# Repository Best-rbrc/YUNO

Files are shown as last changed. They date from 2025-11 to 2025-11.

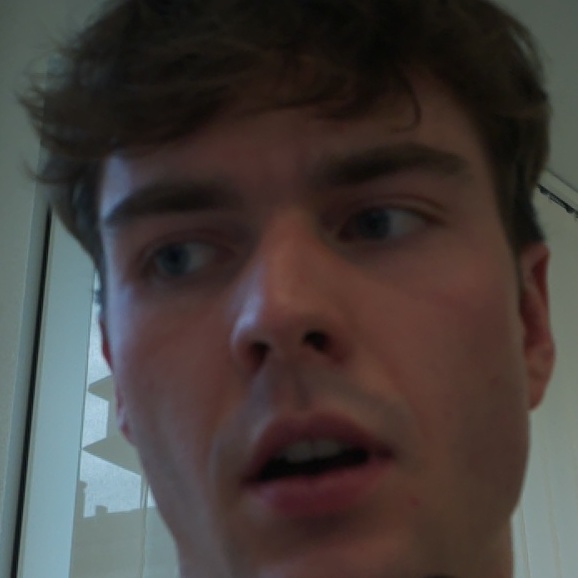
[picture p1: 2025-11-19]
waveshare/cache/photos/person_3.jpg

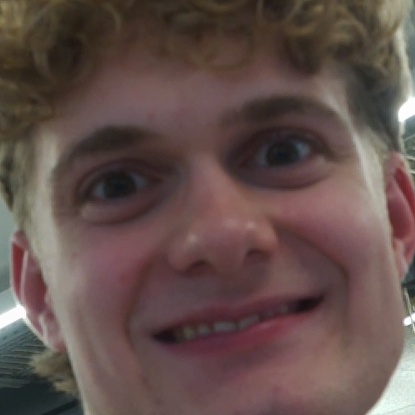
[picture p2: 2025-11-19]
waveshare/cache/photos/person_4.jpg

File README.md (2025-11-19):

# Yuno – Smart Person Recognition & Memory Assistant

Yuno is an intelligent face recognition system that helps you remember people and their context. The project consists of two independent Raspberry Pi systems and a web frontend, all syncing through Supabase as the single source of truth.

## What is Yuno?

**Yuno Glasses Prototype** (Raspberry Pi 1): A portable wearable system with camera, microphone, and Bluetooth speaker that recognizes faces, recalls context about people, and provides audio feedbac and rizz through physical button interactions.

**WaveShare Display Station** (Raspberry Pi 2): A 64x64 RGB LED matrix display showing pixel art portraits of recognized persons with an interactive quiz mode controlled via Arduino joystick.

**Web Dashboard**: A simple browser-based interface for managing persons, viewing photos, and editing context information.

## Key Features

- **Face Recognition**: ArcFace ONNX model with 512-dimensional embeddings and cosine similarity matching
- **Dual Raspberry Pi Architecture**: Independent systems syncing via Supabase (no direct Pi-to-Pi communication)
- **Button-Controlled Operation**: Physical buttons for enrollment and identification (Raspberry Pi 1)
- **Interactive Display**: 64x64 pixel art slideshow with quiz mode (Raspberry Pi 2)
- **Audio Feedback**: Text-to-speech via OpenAI TTS-1 or offline pyttsx3
- **Cloud Sync**: Supabase PostgreSQL database and cloud storage for photos/audio
- **Gender Detection**: DeepFace integration for demographic analysis
- **Rizz Mode**: AI-powered social interaction tips based on person context

---

## Documentation Structure

This project has **comprehensive documentation** across multiple README files:

### **[HARDWARE.md](HARDWARE.md)** - Complete Hardware Setup Guide
Detailed hardware requirements and assembly instructions for:
- **Raspberry Pi 1 (Yuno Glasses)**: Camera, microphone, Bluetooth speaker, physical buttons
- **Raspberry Pi 2 (WaveShare Display)**: 64x64 RGB LED matrix, MQTT broker setup
- **Arduino LCD Controller**: 16x2 display with joystick for quiz control
- Network architecture, MQTT configuration, power requirements, and wiring diagrams

👉 **Read HARDWARE.md for complete hardware setup instructions**

### **[src/README.md](src/README.md)** - Backend Technical Documentation
In-depth technical documentation for all backend modules:
- Face recognition pipeline (ArcFace, embedding generation, matching)
- Identity matching algorithms and similarity thresholds
- Database schema and Supabase integration
- OpenAI API integration (Whisper, GPT-4o-mini, TTS-1)
- Audio recording and speech output systems
- Button handler for Raspberry Pi GPIO
- All 14 core modules with code examples and usage patterns

👉 **Read src/README.md for backend development and API details**

### **[frontend/README.md](frontend/README.md)** - Web Frontend Documentation
Complete guide to the web dashboard:
- Vanilla JavaScript SPA architecture
- Supabase client integration and authentication
- Person management (CRUD operations)
- Photo upload and signed URL generation
- UI/UX design system and responsive layouts
- Context parsing and display logic

👉 **Read frontend/README.md for web interface development**

### **[waveshare/README.md](waveshare/README.md)** - Display System Documentation
WaveShare RGB LED matrix display system:
- Pixel art generation and LED optimization
- Multi-threaded architecture (display, MQTT, quiz, music)
- Quiz mode with OpenAI question generation
- MQTT joystick control integration
- Background music and TTS narration
- Configuration and operation modes

👉 **Read waveshare/README.md for display system details**

## Quick Start

1. Python 3.11 recommended
2. Create and activate a virtual environment
```bash
python -m venv venv
source venv/bin/activate  # macOS/Linux
# .\venv\Scripts\activate  # Windows PowerShell
```
3. Install dependencies
```bash
pip install -r requirements.txt
# If DeepFace/TensorFlow errors occur:
pip install tf-keras
```
4. Add configuration and keys
- Create `config/.env` with:
```
OPENAI_API_KEY=sk-...
SUPABASE_URL=https://YOUR-PROJECT.supabase.co
SUPABASE_KEY=YOUR_SERVICE_ROLE_OR_ANON_KEY
```
- Ensure `config/settings.yaml` exists (language etc.). Example:
```yaml
language: 'de'
```

5. Run
```bash
python main.py enroll             # Enroll new person (audio+photos)
python main.py identify           # Recognize and speak known persons
python main.py identify_local     # Recognize (console only)
python main.py add_face           # Add unknown faces (no audio)
python main.py rizz               # Rizz Mode (camera → gender → tips)
python main.py sync               # Sync local DB with Supabase
python main.py button             # Raspberry Pi button mode
```

---

##  Repository Structure

```
HandsOnHCI/
├── README.md                          # This file - project overview
├── HARDWARE.md                        # Complete hardware setup guide
├── requirements.txt                   # Python dependencies
├── main.py                            # CLI entry point for all operations
│
├── config/                            # Configuration files
│   ├── .env                           # API keys (OpenAI, Supabase) - create this!
│   ├── .env.example                   # Example environment variables template
│   └── settings.yaml                  # App settings (language, thresholds, etc.)
│
├── models/                            # Pre-trained models
│   ├── w600k_r50.onnx                 # ArcFace face recognition model (required)
│   └── README.md                      # Model information and download links
│
├── data/                              # Local data storage (auto-created)
│   ├── database/                      # SQLite database
│   │   └── memory.db                  # Local person database
│   ├── persons/                       # Enrolled person folders
│   │   └── person_X_Name/             # Individual person data
│   │       ├── faces/                 # Face images for training
│   │       ├── embeddings/            # Face embeddings (512-dim vectors)
│   │       └── audio/                 # Audio recordings
│   ├── photos/                        # Temporary photo storage
│   ├── audio/                         # Temporary audio recordings
│   └── temp/                          # Temporary processing files
│
├── src/                               # Backend source code
│   ├── README.md                      # 📖 Detailed backend documentation
│   ├── camera_manager.py              # Camera capture and frame processing
│   ├── face_recognizer.py             # Face detection and embedding generation
│   ├── identity_matcher.py            # Cosine similarity matching (threshold 0.45)
│   ├── database_handler.py            # SQLite database operations
│   ├── person_manager.py              # Person enrollment and identification
│   ├── gender_detector.py             # DeepFace gender/age/emotion detection
│   ├── rizz_mode.py                   # Social interaction tips generation
│   ├── rizz_orchestrator.py           # Rizz mode pipeline
│   ├── openai_api.py                  # OpenAI API (Whisper, GPT-4o, TTS-1)
│   ├── speech_output.py               # Audio playback (pygame, pyttsx3)
│   ├── audio_recorder.py              # Microphone recording (sounddevice)
│   ├── supabase_handler.py            # Supabase database and storage client
│   ├── sync_manager.py                # Bidirectional sync (local ↔ Supabase)
│   ├── input_handler.py               # Raspberry Pi GPIO button handler
│   └── path_manager.py                # File path management utilities
│
├── frontend/                          # Web dashboard
│   ├── README.md                      # 📖 Frontend documentation
│   ├── index.html                     # Single-page web application
│   ├── SUPABASE_SETUP.md              # Supabase configuration guide
│   └── src/
│       └── components/
│           └── PersonCard.jsx         # React component (if migrating)
│
├── waveshare/                         # RGB LED matrix display system
│   ├── README.md                      # 📖 WaveShare display documentation
│   ├── main_app.py                    # Main display application (700+ lines)
│   ├── data_loader.py                 # Fetch persons from Supabase
│   ├── pixel_art_generator.py         # Convert photos to 64x64 pixel art
│   ├── cache/                         # Photo cache directory
│   │   └── photos/                    # Cached person photos (person_X.jpg)
│   ├── sounds/                        # Background music playlist (.wav files)
│   └── simulation_output/             # Test output for debugging
│
├── Arduino/                           # Arduino firmware
│   └── Commands_Senden_UP_RIGHT_LEFT_DOWN/
│       └── Commands_Senden_UP_RIGHT_LEFT_DOWN.ino
│           # Arduino UNO R4 WiFi firmware for LCD display and joystick
│           # Connects to MQTT broker on Raspberry Pi 2 (WaveShare)
│           # Controls: UP/DOWN/LEFT/RIGHT joystick + button press
│           # Displays: Person name and description on 16x2 LCD
│
└── tests/                             # Test scripts for development
    ├── test_face_detection.py         # Test face detection on static images
    ├── test_face_identification.py    # Test face recognition accuracy
    ├── test_face_identification_with_context.py  # Test with person context
    ├── test_gender_detection.py       # Test gender detection on images
    ├── test_gender_video.py           # Test gender detection on video stream
    └── test_gender_with_pickuplines.py  # Test Rizz mode pipeline
```

---

## Quick Start

### Prerequisites
- **Python 3.11+** recommended
- **Raspberry Pi OS** (for hardware systems) or macOS/Linux (for development)
- **Supabase Account** (free tier sufficient)
- **OpenAI API Key** (for TTS and AI features)

### Installation

1. **Clone the repository**:
   ```bash
   git clone https://github.com/Best-rbrc/HandsOnHCI.git
   cd HandsOnHCI
   ```

2. **Create virtual environment**:
   ```bash
   python3 -m venv venv
   source venv/bin/activate  # macOS/Linux
   # .\venv\Scripts\activate  # Windows
   ```

3. **Install dependencies**:
   ```bash
   pip install -r requirements.txt
   # If DeepFace/TensorFlow errors:
   pip install tf-keras
   ```

4. **Configure environment**:
   Create `config/.env` (copy from `config/.env.example`):
   ```bash
   OPENAI_API_KEY=sk-proj-your-api-key-here
   SUPABASE_URL=https://your-project.supabase.co
   SUPABASE_KEY=your-anon-public-key
   ```

5. **Adjust settings** (optional):
   Edit `config/settings.yaml`:
   ```yaml
   language: 'de'  # or 'en'
   similarity_threshold: 0.45
   ```

### Usage Commands

```bash
# Enroll a new person (camera + audio + context)
python main.py enroll

# Identify a person (camera + TTS feedback)
python main.py identify

# Identify without audio (console output only)
python main.py identify_local

# Add face photos only (no audio/context)
python main.py add_face

# Rizz Mode (gender detection + social tips)
python main.py rizz

# Sync local database with Supabase
python main.py sync

# Raspberry Pi button mode (GPIO control)
python main.py button
```

### Hardware Systems

**Raspberry Pi 1 (Yuno Glasses)**:
```bash
# Run in button mode (wait for GPIO button press)
python main.py button
# Press Normal Button (GPIO 17) → Identify
# Press Heartbeat Button (GPIO 27) → Enroll
```

**Raspberry Pi 2 (WaveShare Display)**:
```bash
cd waveshare
python main_app.py
# Displays person slideshow with quiz mode
# Controlled via Arduino joystick (MQTT)
```

**Arduino LCD Controller**:
- Upload firmware from `Arduino/Commands_Senden_UP_RIGHT_LEFT_DOWN/`
- Configure WiFi and MQTT broker IP (Raspberry Pi 2)
- Joystick controls quiz navigation on WaveShare display

---

## Configuration Files

### `config/.env` - API Keys and Secrets
```bash
# OpenAI (required for TTS and text generation)
OPENAI_API_KEY=sk-proj-...

# Supabase (required for cloud sync and frontend)
SUPABASE_URL=https://your-project.supabase.co
SUPABASE_KEY=your-anon-or-service-role-key

# Optional: Raspberry Pi GPIO pins
NORMAL_BUTTON_PIN=17
HEARTBEAT_BUTTON_PIN=27
```

### `config/settings.yaml` - Application Settings

This YAML file controls various runtime parameters for the Yuno system:

```yaml
# Audio Recording Settings
record_duration: 20               # Duration in seconds for audio recording during enrollment
                                  # Used when capturing person context via microphone

# Language Settings
language: "de"                    # Language for TTS output and AI responses ('de' or 'en')
                                  # Affects OpenAI TTS voice and GPT response language

# File Paths (relative to project root)
photo_path: "data/photos/"        # Directory for temporary photo storage during capture
audio_path: "data/audio/"         # Directory for temporary audio recordings
database_path: "data/memory.db"   # SQLite database location (not used if Supabase sync active)

# Audio Hardware Configuration (Raspberry Pi specific)
audio_samplerate: 48000           # Sample rate in Hz (48 kHz standard for USB microphones)
                                  # Note: 44.1 kHz may not work with certain USB devices
audio_device_name: "AB13X USB Audio"  # Explicit USB microphone device name
                                  # Alternative ALSA format: "hw:2,0" (Card 2, Device 0)
                                  # Use `arecord -l` on Raspberry Pi to list available devices
```

**Common Configuration Adjustments**:

- **Change language**: Set `language: "en"` for English TTS and responses
- **Longer context recording**: Increase `record_duration: 30` for more detailed descriptions
- **Different microphone**: Update `audio_device_name` to match your USB device (check with `arecord -l`)
- **Audio issues**: Try different `audio_samplerate` values (44100, 48000, 96000) if recording fails

**Note**: The `database_path` setting is primarily for standalone/offline mode. When Supabase is configured in `.env`, the system automatically syncs with the cloud database.

---

## Testing

The `tests/` folder contains various test scripts for development:

- **`test_face_detection.py`**: Test face detection on static images
- **`test_face_identification.py`**: Test face recognition accuracy on enrolled persons
- **`test_face_identification_with_context.py`**: Test identification with context display
- **`test_gender_detection.py`**: Test gender detection on individual images
- **`test_gender_video.py`**: Test real-time gender detection on video stream
- **`test_gender_with_pickuplines.py`**: Test complete Rizz mode pipeline

Run tests:
```bash
python tests/test_face_detection.py
python tests/test_gender_video.py
```

---

## Database & Cloud Sync

### Supabase Schema
**Table: `persons`**
- `id` (int, primary key)
- `name` (text)
- `gender` (text)
- `context` (text) - Description/notes about the person
- `photo_url` (text) - Public URL to profile photo in Supabase Storage
- `audio_url` (text, optional) - URL to audio recording
- `created_at` (timestamp)

**Storage Buckets**:
- `person-photos`: Profile photos (private, use signed URLs)
- `person-audio`: Audio recordings (optional)

### Sync Behavior
- **Enroll/Identify on Pi 1**: Automatically syncs to Supabase
- **WaveShare Display (Pi 2)**: Fetches persons from Supabase every 5 minutes
- **Frontend**: Directly queries Supabase via JavaScript client
- **Conflict Resolution**: Supabase is the single source of truth

---

## Frontend Dashboard

Access the web dashboard:
```bash
# Option 1: Direct file access
open frontend/index.html  # macOS
start frontend/index.html  # Windows

# Option 2: HTTP server
cd frontend
python3 -m http.server 8000
# Open http://localhost:8000
```

Features:
- View all enrolled persons
- Edit person name and context
- Upload new photos
- Delete persons
- Real-time sync with Supabase
 **See [frontend/README.md](frontend/README.md) for detailed usage**

---

## Development Notes

### Project Structure Philosophy
- **Modular Architecture**: Each module has a single responsibility
- **Supabase as SSoT**: All systems sync via Supabase, no direct inter-Pi communication
- **Dual Operation Modes**: Standalone (Raspberry Pi) and development (Mac/PC)
- **Hardware Abstraction**: Same codebase runs on Pi and desktop with minimal changes

### Key Technologies
- **Face Recognition**: ArcFace ONNX (w600k_r50 model)
- **Face Detection**: OpenCV with Haar cascades
- **Gender/Age Detection**: DeepFace with TensorFlow backend
- **Cloud Backend**: Supabase (PostgreSQL + Storage)
- **AI Services**: OpenAI (Whisper, GPT-4o-mini, TTS-1)
- **Audio**: sounddevice, pygame, pyttsx3
- **Hardware**: Raspberry Pi GPIO, WaveShare RGB LED matrix, Arduino WiFi

### Adding New Features
1. **Backend**: Add module to `src/` and document in `src/README.md`
2. **Frontend**: Extend `frontend/index.html` and update `frontend/README.md`
3. **Hardware**: Update `HARDWARE.md` with wiring and setup instructions
4. **Tests**: Create test script in `tests/` folder

---

## Troubleshooting

### Common Issues

**DeepFace/TensorFlow Error**:
```bash
pip install tf-keras
```

**Camera Not Detected**:
```bash
# Check available cameras
ls /dev/video*  # Linux/Pi
# Or try different camera_index in settings.yaml
```

**Supabase Connection Failed**:
- Verify `SUPABASE_URL` and `SUPABASE_KEY` in `.env`
- Check internet connection
- Ensure Supabase project is active

**Frontend Images Not Loading**:
- Check Supabase Storage bucket permissions
- Ensure signed URLs are generated correctly
- Verify RLS policies allow public access

**MQTT Connection Timeout** (Arduino ↔ Pi 2):
- Verify Raspberry Pi 2 IP address in Arduino code
- Check Mosquitto broker is running: `sudo systemctl status mosquitto`
- Test MQTT: `mosquitto_sub -h localhost -t '#'`

**GPIO Permission Denied** (Raspberry Pi):
```bash
sudo usermod -aG gpio $USER
sudo reboot
```

---

## License & Attribution

- **ArcFace Model**: w600k_r50.onnx from [InsightFace](https://github.com/deepinsight/insightface)
- **DeepFace**: [serengil/deepface](https://github.com/serengil/deepface)
- **Supabase**: [supabase.io](https://supabase.io)
- **OpenAI**: [platform.openai.com](https://platform.openai.com)

---

## Quick Links

-  **[HARDWARE.md](HARDWARE.md)** - Complete hardware setup guide
-  **[src/README.md](src/README.md)** - Backend technical documentation
-  **[frontend/README.md](frontend/README.md)** - Web dashboard guide
-  **[waveshare/README.md](waveshare/README.md)** - Display system documentation
-  **[Arduino Firmware](Arduino/Commands_Senden_UP_RIGHT_LEFT_DOWN/)** - LCD controller code
-  **[Tests Folder](tests/)** - Development test scripts

---

**Built with Love and Rizz for the Yuno Project**

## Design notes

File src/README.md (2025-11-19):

# src/ – Core Application Modules

This folder contains the core logic for camera capture, face recognition, identity matching, database management, Supabase synchronization, OpenAI integration, and specialized modes like Rizz Mode. Each module is designed to be modular and reusable across different application flows.

---

## Table of Contents

1. [Module Overview](#module-overview)
2. [Technology Stack](#technology-stack)
3. [Detailed Module Documentation](#detailed-module-documentation)
4. [Application Pipelines](#application-pipelines)
5. [Configuration](#configuration)
6. [Common Issues & Troubleshooting](#common-issues--troubleshooting)

---

## Module Overview

### Core Recognition & Detection
- **`face_recognizer.py`**: Face detection and embedding extraction using ArcFace ONNX
- **`identity_matcher.py`**: Cosine similarity-based identity matching against database embeddings
- **`gender_detector.py`**: Gender, age, and emotion detection using DeepFace

### Data Management
- **`database_handler.py`**: SQLite database operations for persons, embeddings, and metadata
- **`path_manager.py`**: File system structure management (per-person directories)
- **`supabase_handler.py`**: Supabase PostgreSQL and Storage client
- **`sync_manager.py`**: Bidirectional sync between local SQLite and Supabase

### Input/Output
- **`camera_manager.py`**: Multi-platform camera capture (Raspberry Pi CSI, USB, fallback)
- **`audio_recorder.py`**: Audio recording with sounddevice/pyaudio
- **`speech_output.py`**: Text-to-Speech using OpenAI TTS and pygame playback

### AI Integration
- **`openai_api.py`**: OpenAI API wrapper (Whisper, GPT-4, TTS, Structured Outputs)
- **`rizz_mode.py`**: AI-powered flirting assistant with gender-based tips
- **`rizz_orchestrator.py`**: End-to-end Rizz Mode pipeline orchestration

### High-Level Flows
- **`person_manager.py`**: Orchestrates enroll, identify, and add_face workflows
- **`input_handler.py`**: Raspberry Pi GPIO button listener for triggering actions

---

## Technology Stack

### Computer Vision & Face Recognition
- **OpenCV (`cv2`)**: Image processing, camera capture, face detection
- **ONNX Runtime (`onnxruntime`)**: Runs ArcFace model for face embeddings
- **ArcFace ONNX Model (`w600k_r50.onnx`)**: Pre-trained face recognition model generating 512-dimensional embeddings
- **Haar Cascade**: Fast frontal face detection (from OpenCV)
- **DeepFace**: Multi-task facial analysis (gender, age, emotion, race)

### Audio Processing
- **sounddevice**: Cross-platform audio recording (primary, macOS/Linux)
- **pyaudio**: Audio recording fallback (Raspberry Pi)
- **wave**: WAV file writing
- **pygame**: Audio playback for TTS

### AI & NLP
- **OpenAI API**:
  - **Whisper**: Audio transcription (multilingual)
  - **GPT-4o-mini**: Text analysis, greeting generation, conversation analysis
  - **TTS-1**: Text-to-Speech with multiple voices
  - **Structured Outputs**: JSON schema validation for reliable parsing
  
### Database & Backend
- **SQLite3**: Local embedded database for persons and embeddings
- **Supabase Python Client**: PostgreSQL database and cloud storage integration
- **pickle**: Python object serialization (embeddings as BLOBs)

### Utilities
- **NumPy**: Numerical operations, array handling, embedding normalization
- **Pillow (PIL)**: Image manipulation, brightness enhancement, rotation
- **python-dotenv**: Environment variable management
- **PyYAML**: Configuration file parsing

---

## Detailed Module Documentation

### `camera_manager.py`

**Purpose**: Cross-platform camera capture with intelligent fallback mechanisms.

**Key Features**:
- **Raspberry Pi CSI Camera**: Primary method using `rpicam-still` (Pi 5) or `libcamera-still` (older Pi versions)
- **USB Camera Fallback**: Uses OpenCV `VideoCapture` on non-Pi systems
- **Auto-Brightness**: Detects dark images and applies automatic brightness enhancement
- **180° Rotation**: Built-in image rotation for camera mounting orientation
- **Multi-Photo Capture**: Callback-based function for capturing multiple photos during audio recording
- **Camera Availability Check**: Pre-flight check to detect camera hardware

**Technologies Used**:
- `subprocess` for calling system camera utilities (`rpicam-still`, `libcamera-still`)
- OpenCV for USB camera capture and brightness analysis
- Pillow for image enhancement and rotation
- NumPy for brightness calculations

**Configuration**:
- Camera resolution: 1920x1080 (Full HD)
- Timeout: 2 seconds for capture
- No preview mode (headless operation)

---

### `face_recognizer.py`

**Purpose**: Face detection and embedding extraction using ArcFace ONNX model.

**Key Features**:
- **ArcFace Model**: State-of-the-art face recognition with 512-dimensional embeddings
- **Haar Cascade Detection**: Fast face detection with configurable strictness
- **Face Validation**: Multi-criteria validation to reduce false positives:
  - Aspect ratio check (0.6-1.5)
  - Minimum size threshold (100x100 pixels)
  - Brightness variance check
  - Image quality validation
- **Center-Priority Selection**: Prioritizes faces closest to frame center
- **Multi-Face Support**: Can detect and process all faces in a frame
- **Preprocessing Pipeline**: BGR→RGB conversion, normalization to [-1,1], CHW format
- **L2 Normalization**: Embeddings are normalized for cosine similarity

**Technologies Used**:
- **ONNX Runtime**: Efficient model inference
- **OpenCV Haar Cascade**: `haarcascade_frontalface_default.xml`
- **NumPy**: Embedding normalization and array operations

**Model Specifications**:
- Input: 112×112 RGB image (CHW format)
- Output: 512-dimensional float32 embedding
- Normalization: L2 (unit vector)

**Detection Parameters**:
- Scale factor: 1.1
- Min neighbors: 7 (higher = fewer false positives)
- Min size: 100×100 pixels

---

### `identity_matcher.py`

**Purpose**: Match face embeddings against stored database embeddings using cosine similarity.

**Key Features**:
- **Cosine Similarity**: Dot product of L2-normalized embeddings
- **Threshold-Based Matching**: Default threshold of 0.45 (configurable)
- **Best Candidates**: Returns top 3 matches with similarity scores
- **Suggestion Threshold**: 0.40 for "best guess" when no confident match

**Technologies Used**:
- **NumPy**: Dot product calculation
- **SQLite3**: Database queries for stored embeddings
- **pickle**: Deserialization of BLOB embeddings

**Matching Logic**:
```python
similarity = np.dot(embedding1, embedding2)  # For normalized embeddings
if similarity >= 0.45:  # Match found
    return person_id, name, similarity
```

**Similarity Ranges**:
- 0.90-1.00: Very high confidence (same person)
- 0.70-0.89: High confidence
- 0.45-0.69: Match threshold
- 0.40-0.44: Suggestion only
- < 0.40: No match

---

### `database_handler.py`

**Purpose**: SQLite database operations for person records and face embeddings.

**Schema**:
```sql
CREATE TABLE persons (
    id INTEGER PRIMARY KEY,
    name TEXT,
    context TEXT,
    photo_path TEXT,
    audio_path TEXT,
    embedding BLOB,  -- Pickled NumPy array
    created_at TIMESTAMP DEFAULT CURRENT_TIMESTAMP,
    updated_at TIMESTAMP DEFAULT CURRENT_TIMESTAMP
);

CREATE TABLE sync_metadata (
    key TEXT PRIMARY KEY,
    value TEXT,
    updated_at TIMESTAMP DEFAULT CURRENT_TIMESTAMP
);
```

**Key Functions**:
- `init_db()`: Create tables if not exist
- `add_person()`: Insert new person with embedding
- `update_person()`: Update person data (appends context, replaces files)
- `get_person_by_id()`: Retrieve person details
- `get_all_embeddings()`: Fetch all embeddings for matching
- `bulk_insert_persons()`: Efficient batch insert for sync
- `get/set_local_db_version()`: Version tracking for sync

**Technologies Used**:
- **SQLite3**: Embedded SQL database
- **pickle**: Embedding serialization/deserialization
- **NumPy**: Embedding array handling

**Location**: `data/database/memory.db`

---

###  `path_manager.py`

**Purpose**: Manages file system structure with per-person directories.

**Directory Structure**:
```
data/
├── database/
│   └── memory.db
└── persons/
    ├── person_1_MaxMustermann/
    │   ├── profile.jpg
    │   ├── audio.wav
    │   └── faces/
    │       ├── face_001.jpg
    │       ├── face_002.jpg
    │       └── ...
    ├── person_2_AnnaSchmidt/
    └── ...
```

**Key Features**:
- **Name Sanitization**: Removes special characters from names
- **Person Directory Creation**: `person_{id}_{name}/` format
- **Face Collection**: Separate `faces/` subdirectory for multiple face images
- **Path Resolution**: Centralized path management for all modules

**Technologies Used**:
- **os/pathlib**: File system operations
- **re**: Regular expressions for name sanitization

---

###  `supabase_handler.py`

**Purpose**: Supabase PostgreSQL and Storage integration for cloud sync.

**Key Features**:
- **Database Operations**: CRUD operations on `persons` table
- **Storage Management**: Upload/download photos and audio files
- **Signed URLs**: Generate temporary URLs for private storage buckets
- **Embedding Serialization**: Hex encoding for BYTEA column
- **Error Handling**: Graceful fallback when Supabase unavailable

**Technologies Used**:
- **supabase-py**: Official Python client
- **pickle**: Embedding serialization
- **requests**: HTTP operations for signed URLs

**Storage Buckets**:
- `persons-photos`: Profile images
- `persons-audio`: Audio recordings

**Environment Variables**:
- `SUPABASE_URL`: Project URL
- `SUPABASE_KEY`: Service role or anon key

---

###  `sync_manager.py`

**Purpose**: Bidirectional synchronization between local SQLite and Supabase.

**Sync Strategies**:
1. **Pull from Supabase**: Download all persons and files to local
2. **Push to Supabase**: Upload local persons and files to cloud
3. **Version Tracking**: Prevents unnecessary re-downloads

**Key Features**:
- **File Downloads**: Parallel download of photos and audio
- **Local Caching**: Avoids re-downloading unchanged files
- **Batch Operations**: Efficient bulk inserts
- **Auto-Retry**: Handles transient network errors
- **Background Sync**: Can run as daemon process

**Technologies Used**:
- **SupabaseHandler**: Cloud operations
- **DatabaseHandler**: Local operations
- **PathManager**: File system management
- **datetime/timedelta**: Cooldown periods

---

###  `audio_recorder.py`

**Purpose**: Cross-platform audio recording with real-time callbacks.

**Key Features**:
- **Platform Detection**: Automatically selects sounddevice (macOS/Linux) or pyaudio (Pi)
- **Device Selection**: By name or ID from configuration
- **Progress Callbacks**: Real-time elapsed time updates
- **Quality Settings**: 44.1kHz sample rate (CD quality)
- **Volume Check**: Warns if recording is too quiet
- **Thread-Safe**: Callback execution in separate thread

**Technologies Used**:
- **sounddevice**: Primary audio library (preferred)
- **pyaudio**: Fallback for Raspberry Pi
- **wave**: WAV file encoding
- **threading**: Callback management
- **NumPy**: Audio level analysis

**Configuration** (`settings.yaml`):
- `record_duration`: Recording length (default: 20s)
- `audio_samplerate`: Sample rate (default: 44100 Hz)
- `audio_device_name`: Optional device name
- `audio_device_id`: Optional device ID

---

### `speech_output.py`

**Purpose**: Text-to-Speech output using OpenAI TTS and pygame playback.

**Key Features**:
- **OpenAI TTS-1**: High-quality voice synthesis
- **Voice Selection**: 6 voices (alloy, echo, fable, onyx, nova, shimmer)
- **Greeting Generation**: Personalized greetings with GPT-4o-mini
- **Memory Context**: Reminders about when/where user met someone
- **Temporary Files**: Auto-cleanup of MP3 files
- **Fallback**: Prints to console if pygame unavailable

**Technologies Used**:
- **OpenAI TTS-1**: Text-to-speech model
- **pygame.mixer**: Audio playback
- **tempfile**: Temporary MP3 storage

**Voice Characteristics**:
- **alloy**: Neutral, balanced (default)
- **echo**: Clear, articulate
- **fable**: Warm, expressive
- **onyx**: Deep, authoritative
- **nova**: Energetic, friendly
- **shimmer**: Soft, gentle

---

###  `openai_api.py`

**Purpose**: Centralized OpenAI API client with specialized functions.

**Key Functions**:

1. **`transcribe_audio(file_path)`**: 
   - Uses Whisper-1 model
   - Language: Configured in `settings.yaml`
   - Returns: Transcript text

2. **`analyze_text(text)`**:
   - Uses GPT-4o-mini with Structured Outputs
   - JSON Schema validation for guaranteed format
   - Returns: `{name, thema, stimmung, kontext}`

3. **`generate_speech_audio(text, voice)`**:
   - TTS-1 model with selectable voice
   - Returns: MP3 audio bytes

4. **`generate_greeting_text(person_data)`**:
   - Personalized memory reminders
   - Uses "Du" form (German informal)
   - Context: Name, when met, relationship
   - Returns: 2-3 sentence greeting

**Technologies Used**:
- **OpenAI Python SDK**: Official client library
- **Structured Outputs**: JSON schema enforcement
- **python-dotenv**: API key management

**Models Used**:
- **whisper-1**: Audio transcription
- **gpt-4o-mini**: Text generation (cost-effective)
- **tts-1**: Text-to-speech

---

###  `gender_detector.py`

**Purpose**: Gender, age, emotion, and race detection using DeepFace.

**Key Features**:
- **Multi-Task Analysis**: Gender, age, emotion, race in one pass
- **Multiple Models**: VGG-Face (default), ArcFace, Facenet, Dlib, OpenFace
- **Batch Processing**: Can analyze multiple faces
- **Confidence Scores**: Returns probability distributions
- **Fallback Handling**: Graceful degradation if face not detected

**Technologies Used**:
- **DeepFace**: Facial attribute analysis library
- **TensorFlow/Keras**: Backend for DeepFace models
- **tf-keras**: Compatibility layer

**Analysis Output**:
```python
{
    "gender": {"Woman": 0.87, "Man": 0.13},
    "dominant_gender": "Woman",
    "age": 28,
    "emotion": {"happy": 0.65, "neutral": 0.25, ...},
    "dominant_emotion": "happy",
    "race": {"asian": 0.01, "white": 0.85, ...},
    "dominant_race": "white"
}
```

**Models**:
- **VGG-Face**: Most accurate, slower
- **ArcFace**: Fast, accurate
- **Facenet**: Balanced
- **Dlib**: Lightweight

---

###  `rizz_mode.py` & `rizz_orchestrator.py`

**Purpose**: AI-powered flirting assistant with context-aware pickup lines.

**Rizz Mode Class** (`rizz_mode.py`):
- **Gender Detection**: Uses DeepFace to determine target gender
- **Personalized Tips**: GPT-4o-mini generates culturally appropriate tips
- **Structured Output**: JSON schema for guaranteed parsing
- **Context Integration**: Uses known person context if available
- **German Language**: Tips in German with appropriate tone

**Rizz Orchestrator** (`rizz_orchestrator.py`):
- **End-to-End Pipeline**: Camera → Face Detection → Identity Matching → Gender Detection → Tip Generation
- **No DB Writes**: Unknown persons are not persisted (privacy-focused)
- **Speech Output**: Speaks both person context and tips
- **Error Handling**: Graceful fallback at each step

**Technologies Used**:
- **OpenAI GPT-4o-mini**: Tip generation
- **DeepFace**: Gender detection
- **ArcFace**: Face recognition (for known persons)
- **TTS**: Spoken output

**Output Format**:
```json
{
    "tips": [
        {"tip": "Kompliment zu ihrer Ausstrahlung", "kategorie": "Eröffnung"},
        {"tip": "Frage nach ihrem Lieblingshobby", "kategorie": "Gesprächseinstieg"},
        {"tip": "Augenkontakt halten", "kategorie": "Körpersprache"}
    ]
}
```

---

### `person_manager.py`

**Purpose**: High-level orchestration of person enrollment, identification, and face addition.

**Workflows**:

1. **`enroll_person()`**:
   - Audio recording (20s with progress callback)
   - Multi-photo capture during recording
   - Whisper transcription
   - GPT-4o text analysis (name, context extraction)
   - Face detection and selection (center-priority)
   - Embedding generation
   - Database persistence
   - Directory structure creation
   - Optional Supabase upload

2. **`identify_person()`**:
   - Photo capture
   - Multi-face detection
   - Embedding extraction for each face
   - Database matching with similarity threshold
   - Personalized greeting generation
   - Speech output (known persons)
   - Console output (unknown persons)

3. **`identify_local()`**:
   - Same as identify but without speech output
   - Console-only mode for testing

4. **`add_face()`**:
   - Photo capture
   - Face detection
   - Check against database (unknown persons only)
   - Directory creation without audio
   - Store face with minimal metadata

**Technologies Used**:
- Orchestrates: `camera_manager`, `audio_recorder`, `face_recognizer`, `identity_matcher`, `database_handler`, `openai_api`, `speech_output`

---

### `input_handler.py`

**Purpose**: Raspberry Pi GPIO button listener for physical interaction.

**Key Features**:
- **Button Debouncing**: Prevents multiple triggers
- **Action Mapping**: Different actions for short/long press
- **Background Thread**: Non-blocking button monitoring
- **Camera Check**: Pre-flight camera availability test
- **Auto-Sync**: Periodic Supabase synchronization

**Actions**:
- **Short Press**: Identify person
- **Long Press**: Enroll new person

**Technologies Used**:
- **GPIO libraries**: RPi.GPIO or similar
- **threading**: Background monitoring
- **time**: Debouncing and timing

---

## Application Pipelines

### Enroll Pipeline (`python main.py enroll`)

**Purpose**: Register a new person with audio context and face embeddings.

**Steps**:
1. **Audio Recording** (20 seconds)
   - User speaks about the person
   - Progress displayed in console
   
2. **Multi-Photo Capture**
   - 3-5 photos taken during audio recording
   - Each photo triggers face detection
   
3. **Transcription & Analysis**
   - Whisper transcribes audio to text
   - GPT-4o extracts: name, topic, mood, context
   
4. **Face Detection**
   - All photos analyzed for faces
   - Center-priority selection for profile photo
   - Face validation to eliminate false positives
   
5. **Embedding Generation**
   - ArcFace model generates 512-dim embedding
   - L2 normalization for cosine similarity
   
6. **Database Persistence**
   - SQLite record created
   - Person ID generated
   - Embedding stored as BLOB
   
7. **File Organization**
   - Directory created: `data/persons/person_{id}_{name}/`
   - Profile photo saved
   - Audio file saved
   - Additional faces stored in `faces/` subfolder
   
8. **Cloud Sync** (Optional)
   - Upload to Supabase if configured
   - Photos → Storage bucket
   - Metadata → PostgreSQL table
   - Embedding → BYTEA column (hex-encoded)

**Error Handling**:
- No face detected: Offers retry or manual photo
- Transcription failure: Uses fallback name "Unknown"
- Database error: Transaction rollback

---

### Identify Pipeline (`python main.py identify`)

**Purpose**: Recognize known persons from camera and provide context.

**Steps**:
1. **Photo Capture**
   - Single photo from camera
   - Auto-brightness adjustment
   
2. **Multi-Face Detection**
   - Haar Cascade detects all faces
   - Quality validation for each face
   - Bounding boxes extracted
   
3. **Embedding Extraction**
   - ArcFace processes each detected face
   - 512-dim embeddings generated
   - L2 normalization applied
   
4. **Database Matching**
   - Compare against all stored embeddings
   - Cosine similarity calculation
   - Threshold: 0.45 for positive match
   
5. **Result Processing**
   - **Known Person**:
     - Fetch person data (name, context, created_at)
     - Generate personalized greeting with GPT-4o
     - Speak greeting with OpenAI TTS
     - Display similarity score
   - **Unknown Person**:
     - Display "Unknown person" message
     - Show best candidates if similarity > 0.40
     - Console output only (no speech)
   
6. **Visual Feedback**
   - Bounding boxes drawn on photo
   - Name labels for known persons
   - Similarity scores displayed
   - Color coding: green (known), red (unknown)

**Performance**:
- Face detection: ~100-200ms
- Embedding extraction: ~50-100ms per face
- Database matching: ~10-50ms
- Total latency: ~500ms (excluding speech generation)

---

### Rizz Mode Pipeline (`python main.py rizz`)

**Purpose**: Generate gender-based flirting tips for social situations.

**Steps**:
1. **Photo Capture**
   - Single photo from camera
   
2. **Center Face Detection**
   - Prioritizes face closest to center
   - Ensures single-person targeting
   
3. **Identity Check** (Optional)
   - Attempt to match against database
   - If known: Retrieve context and relationship info
   - If unknown: Proceed without context
   
4. **Gender Detection**
   - DeepFace analyzes face
   - Returns: gender, age, emotion
   - Confidence scores provided
   
5. **Tip Generation**
   - GPT-4o-mini creates personalized tips
   - Input: gender, age (optional), known context (optional)
   - Output: 3-5 structured tips in German
   - Categories: Eröffnung, Gesprächseinstieg, Körpersprache, Komplimente
   
6. **Speech Output**
   - If known person: Speak context first
   - Speak generated tips
   - OpenAI TTS with "alloy" voice
   
7. **Privacy**
   - **No database writes** for unknown persons
   - Tips are ephemeral (not stored)
   - No photos saved

**Tip Structure**:
```json
{
    "tips": [
        {
            "tip": "Authentisches Kompliment zu ihrer Ausstrahlung",
            "kategorie": "Eröffnung"
        },
        {
            "tip": "Frage nach ihrem Lieblingsreiseziel",
            "kategorie": "Gesprächseinstieg"
        },
        {
            "tip": "Offene Körperhaltung zeigen",
            "kategorie": "Körpersprache"
        }
    ]
}
```

---

## Configuration

### Environment Variables (`config/.env`)

```bash
# OpenAI Configuration (Required)
OPENAI_API_KEY=sk-proj-...

# Supabase Configuration (Optional, for cloud sync)
SUPABASE_URL=https://your-project.supabase.co
SUPABASE_KEY=eyJhbGc...  # Service role key preferred
```

### Settings File (`config/settings.yaml`)

```yaml
# Language for Whisper transcription and TTS
language: 'de'  # 'de' for German, 'en' for English

# Audio Recording Settings
record_duration: 20  # seconds
audio_samplerate: 44100  # Hz (CD quality)

# Optional: Specific audio device
# audio_device_name: "USB Microphone"  # Device name (partial match)
# audio_device_id: 0  # Or device ID

# OpenAI Voice Selection
tts_voice: "alloy"  # alloy, echo, fable, onyx, nova, shimmer
```

---

## Common Issues & Troubleshooting

###  DeepFace / TensorFlow Errors

**Error**: `AttributeError: module 'keras.api._v2.keras.xxx' has no attribute 'yyy'`

**Solution**:
```bash
pip install tf-keras
```

**Explanation**: DeepFace requires TensorFlow's Keras implementation. Recent TensorFlow versions need the `tf-keras` compatibility package.

---

###  Missing ArcFace Model

**Error**: `FileNotFoundError: Model not found: models/w600k_r50.onnx`

**Solution**:
1. Ensure `models/` directory exists in project root
2. Download the ArcFace ONNX model:
   ```bash
   cd models
   # Download from official source or use provided model
   ```
3. Verify file exists: `ls -lh models/w600k_r50.onnx`

**Model Specs**:
- Size: ~166 MB
- Format: ONNX (cross-platform)
- Architecture: ResNet-50 backbone

---

###  Raspberry Pi Camera Not Detected

**Error**: `no cameras available`

**Solution**:
1. Enable camera interface:
   ```bash
   sudo raspi-config
   # → Interface Options → Camera → Enable
   # Reboot after enabling
   ```

2. Test camera:
   ```bash
   rpicam-hello --timeout 2000
   ```

3. Check camera connection:
   - CSI cable firmly connected to port J4
   - Blue side of ribbon facing USB ports
   - Camera module compatible with Pi 5

4. Update firmware:
   ```bash
   sudo apt update
   sudo apt upgrade
   sudo rpi-update
   ```

---

###  No Audio Playback (Headless Systems)

**Issue**: pygame mixer not available on headless Raspberry Pi

**Behavior**: 
- TTS text printed to console
- No audio playback
- Application continues normally

**Solution** (if audio needed):
1. Install ALSA libraries:
   ```bash
   sudo apt-get install libasound2-dev
   ```

2. Configure audio output:
   ```bash
   sudo raspi-config
   # → System Options → Audio → Select output device
   ```

3. Test audio:
   ```bash
   speaker-test -t wav -c 2
   ```

---

###  Supabase Connection Failures

**Error**: Connection timeout or authentication failure

**Checklist**:
1. Verify `.env` file exists in `config/` directory
2. Check `SUPABASE_URL` format: `https://xxx.supabase.co`
3. Verify `SUPABASE_KEY` is service role key (full access) or anon key with RLS policies
4. Test connection:
   ```bash
   python -c "from src.supabase_handler import SupabaseHandler; h = SupabaseHandler(); print(h.client)"
   ```

5. Check Supabase project status in dashboard
6. Verify RLS policies allow your operations

---

### Low Face Recognition Accuracy

**Issue**: Faces not matching correctly or too many false positives

**Tuning Parameters** in `face_recognizer.py`:

1. **Detection Strictness**:
   ```python
   # Increase minNeighbors to reduce false positives
   faces = self.face_cascade.detectMultiScale(
       gray, 
       scaleFactor=1.1, 
       minNeighbors=7,  # Default: 7, Higher = stricter
       minSize=(100, 100)  # Minimum face size
   )
   ```

2. **Matching Threshold** in `identity_matcher.py`:
   ```python
   THRESHOLD = 0.45  # Default: 0.45
   # Lower = more strict (fewer false matches)
   # Higher = more lenient (more matches but less accurate)
   ```

3. **Image Quality**:
   - Ensure good lighting
   - Face directly facing camera
   - Minimal occlusion (no masks, sunglasses)
   - Distance: 0.5-2 meters from camera

---

###  Database Lock Errors

**Error**: `sqlite3.OperationalError: database is locked`

**Causes**:
- Multiple processes accessing database simultaneously
- Long-running transaction

**Solutions**:
1. Ensure only one instance of application running
2. Add timeout to connections:
   ```python
   conn = sqlite3.connect(db_path, timeout=10.0)
   ```
3. Close connections properly:
   ```python
   conn.close()  # Always close after operations
   ```

---

###  Audio Recording Too Quiet

**Issue**: Whisper transcription fails due to low audio level

**Solutions**:
1. Check microphone selection in `settings.yaml`:
   ```yaml
   audio_device_name: "Your Microphone Name"
   ```

2. List available devices:
   ```python
   import sounddevice as sd
   print(sd.query_devices())
   ```

3. Increase system microphone gain:
   - **macOS**: System Preferences → Sound → Input → Input Volume
   - **Linux**: `alsamixer` → F4 (capture) → adjust levels
   - **Raspberry Pi**: `alsamixer` → adjust capture levels

4. Check recording level warning:
   ```
   ⚠️  Warnung: Aufnahme sehr leise! Prüfe Mikrofon-Lautstärke.
   Max Pegel: 3.2%  # Should be > 5%
   ```

---

## Performance Metrics

**Typical Latency** (Raspberry Pi 5):
- Photo capture: 1-2 seconds
- Face detection: 100-200ms
- Embedding extraction: 50-100ms per face
- Database matching: 10-50ms
- Total identification: ~2-3 seconds

**Typical Latency** (MacBook Pro M1):
- Photo capture: <100ms
- Face detection: 20-50ms
- Embedding extraction: 10-20ms per face
- Database matching: 5-10ms
- Total identification: ~200-500ms

**Model Sizes**:
- ArcFace ONNX: ~166 MB
- DeepFace models: 150-300 MB (cached on first use)

**Database Size**:
- Per person: ~500 KB - 2 MB (depends on photo quality)
- Embedding: 2 KB (512 floats × 4 bytes)
- 100 persons ≈ 50-200 MB total

---

##  Privacy & Security Notes

1. **Local-First**: All data stored locally by default
2. **Optional Cloud**: Supabase sync is opt-in
3. **Embedding Security**: Embeddings cannot be reversed to reconstruct faces
4. **No Tracking**: No analytics or external tracking
5. **Rizz Mode Privacy**: Unknown persons not saved to database
6. **Audio Cleanup**: Temporary audio files deleted after processing
7. **API Keys**: Keep `.env` file out of version control (add to `.gitignore`)

---

## Additional Resources

- **ArcFace Paper**: [ArcFace: Additive Angular Margin Loss for Deep Face Recognition](https://arxiv.org/abs/1801.07698)
- **DeepFace Documentation**: [https://github.com/serengil/deepface](https://github.com/serengil/deepface)
- **OpenAI API Docs**: [https://platform.openai.com/docs](https://platform.openai.com/docs)
- **Supabase Docs**: [https://supabase.com/docs](https://supabase.com/docs)

---

## Contributing

When modifying modules, follow these principles:
1. **Separation of Concerns**: Each module has a single responsibility
2. **Error Handling**: Always provide graceful fallbacks
3. **Logging**: Use descriptive print statements or logging
4. **Type Hints**: Add type hints for function parameters and returns
5. **Documentation**: Update docstrings when changing behavior

---

**Last Updated**: November 2025

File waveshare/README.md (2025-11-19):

# WaveShare RGB Matrix Display System

Comprehensive display system for WaveShare RGB P3 Matrix Panel 64x64 HUB75 connected to Raspberry Pi 5. Features interactive quiz mode with OpenAI integration, MQTT joystick controls, text-to-speech narration, pixel art rendering, and multi-threaded slideshow management.

---

## Table of Contents

1. [Overview](#overview)
2. [Architecture](#architecture)
3. [Core Modules](#core-modules)
4. [Technologies](#technologies)
5. [Hardware Requirements](#hardware-requirements)
6. [Installation](#installation)
7. [Configuration](#configuration)
8. [Usage](#usage)
9. [Features](#features)
10. [File Structure](#file-structure)

---

## Overview

The WaveShare display system transforms the Yuno face recognition project into an interactive RGB LED matrix experience. It fetches recognized persons from Supabase, generates 64x64 pixel art portraits, and displays them in a continuous slideshow with optional quiz mode for interactive learning.

**Key Capabilities:**
- **Pixel Art Rendering**: Converts photos to 64x64 LED-optimized pixel art with contrast enhancement
- **Interactive Quiz Mode**: OpenAI-powered questions with TTS narration and MQTT joystick controls
- **Real-time Data Sync**: Fetches person data from Supabase database with photo caching
- **Multi-threaded Architecture**: Separate threads for display rendering, MQTT listener, and quiz management
- **Background Music**: Playlist support with crossfade transitions
- **Landing Screen**: Animated welcome screen with brand identity

---

## Architecture

### System Components

```
┌─────────────────────────────────────────────────────────────┐
│                    main_app.py (Main App)                   │
├─────────────────────────────────────────────────────────────┤
│  • RGB Matrix Control (PioMatter driver)                    │
│  • MQTT Listener Thread (Joystick input)                    │
│  • Quiz Queue Thread (OpenAI + TTS)                         │
│  • Background Music Thread (Playlist mgmt)                  │
│  • Slideshow State Machine (Landing/Quiz/Display)           │
└────────┬────────────────────────────────────┬───────────────┘
         │                                    │
    ┌────▼────────┐                    ┌─────▼──────────┐
    │ DataLoader  │                    │ PixelArtGen    │
    │             │                    │                │
    │ • Supabase  │                    │ • PIL Resize   │
    │   fetch     │                    │ • Contrast++   │
    │ • Photo     │                    │ • Color        │
    │   download  │                    │   quantize     │
    │ • Caching   │                    │ • NumPy array  │
    └─────────────┘                    └────────────────┘
         │                                    │
         │            ┌──────────────┐        │
         └────────────►  Supabase    ◄────────┘
                      │              │
                      │ • Persons DB │
                      │ • Photo URLs │
                      │ • Context    │
                      └──────────────┘

External Integrations:
┌──────────────┐     ┌──────────────┐     ┌──────────────┐
│ MQTT Broker  │     │ OpenAI API   │     │ pyttsx3 TTS  │
│ (Joystick)   │     │ (Quiz Gen)   │     │ (Narration)  │
└──────────────┘     └──────────────┘     └──────────────┘
```

### Threading Model

- **Main Thread**: Runs display loop (landing screen → slideshow → quiz mode)
- **MQTT Thread**: Listens for joystick commands (UP/DOWN/LEFT/RIGHT), updates state
- **Quiz Thread**: Pre-generates quiz questions in background for seamless transitions
- **Music Thread**: Manages background music playback with fade transitions

### State Machine

```
┌──────────────┐
│   LANDING    │ (5 seconds)
│   SCREEN     │
└──────┬───────┘
       │
       ▼
┌──────────────┐     Quiz Mode?
│  SLIDESHOW   │────────────┐
│  (Persons)   │            │
└──────┬───────┘            │
       │                    ▼
       │             ┌──────────────┐
       │             │  QUIZ MODE   │
       │             │  (Questions) │
       │             └──────┬───────┘
       │                    │
       └────────────────────┘
```

---

## Core Modules

### `main_app.py`

The primary application orchestrating the entire display system.

**Classes:**
- `YunoDisplayApp`: Main application class managing all subsystems

**Key Methods:**
- `init_hardware()`: Initializes RGB matrix display (64x64, PioMatter driver)
- `init_mqtt()`: Sets up MQTT client for joystick communication (broker: localhost:1883)
- `on_message()`: MQTT callback handler for joystick events (UP/DOWN/LEFT/RIGHT)
- `render_landing_frame()`: Draws animated landing screen with YUNO branding
- `render_person_on_matrix()`: Displays person pixel art with name text overlay
- `speak_context()`: TTS narration of person context using OpenAI or pyttsx3
- `generate_quiz_for_person()`: OpenAI GPT-4o-mini question generation
- `present_quiz_question()`: Renders quiz question with answer options on LED matrix
- `init_quiz_queue()`: Background thread for pre-generating quiz questions
- `play_background_music()`: Playlist manager with crossfade and volume control
- `run()`: Main application loop with state management

**Configuration Constants:**
- `MATRIX_WIDTH = 64`, `MATRIX_HEIGHT = 64`
- `BRIGHTNESS = 50` (0-100 scale)
- `DISPLAY_DURATION = 5` (seconds per person)
- `LANDING_DURATION = 5` (seconds on startup)
- `QUIZ_DISPLAY_DURATION = 15` (seconds per question)
- `MQTT_TOPIC = "waveshare/commands"` (joystick input topic)

**Threading:**
- MQTT listener runs in daemon thread
- Quiz queue runs in daemon thread with queue size 3
- Background music runs in daemon thread

### `data_loader.py`

Handles Supabase integration for fetching person data and downloading photos.

**Classes:**
- `DataLoader`: Supabase client wrapper for person data management

**Key Methods:**
- `is_connected()`: Verifies Supabase connection status
- `fetch_all_persons()`: Retrieves all persons from `persons` table
- `download_photo(photo_url, person_id)`: Downloads photo from Supabase storage
- `load_persons_with_photos()`: Fetches persons and downloads photos with caching
- `clear_cache()`: Clears local photo cache directory

**Caching Strategy:**
- Photos cached in `waveshare/cache/photos/` as `person_{id}.jpg`
- Cache persists across runs for performance
- Downloads only if photo not already cached
- Uses Supabase Storage API with signed URLs

**Dependencies:**
- `src.supabase_handler.SupabaseHandler` for database access
- Requires `SUPABASE_URL` and `SUPABASE_KEY` in environment

### `pixel_art_generator.py`

Converts photos to 64x64 pixel art optimized for RGB LED matrix display.

**Classes:**
- `PixelArtGenerator`: Image processing pipeline for LED matrix

**Key Methods:**
- `load_image(image_path)`: Loads image and converts to RGB
- `resize_with_preserve_aspect()`: Letterboxing resize (no cropping)
- `enhance_contrast(factor=1.8)`: Boosts contrast for LED visibility
- `reduce_colors(palette_size=64)`: Quantizes colors for pixel art effect
- `generate_pixel_art(image_path)`: Full pipeline returning NumPy array
- `pixel_art_to_matrix_format()`: Clips values to 0-255 uint8 range

**Image Processing Pipeline:**
1. Load image → Convert to RGB
2. Resize to 64x64 with letterboxing (preserve aspect ratio, black borders)
3. Enhance contrast by 1.8x for LED brightness
4. Reduce to 64 colors using quantization
5. Return as NumPy array (64, 64, 3) with RGB values 0-255

**Technology:**
- **PIL (Pillow)**: Image loading, resizing with LANCZOS resampling
- **NumPy**: Array manipulation for matrix display
- **Quantization**: Reduces color palette for retro pixel art aesthetic

---

## Technologies

### Hardware Integration
- **adafruit_blinka_raspberry_pi5_piomatter**: RGB LED matrix driver for Raspberry Pi 5
  - Used for direct control of WaveShare P3 HUB75 panel
  - Handles PWM signal generation for LED brightness
  - Supports 64x64 resolution at 50% brightness

### Communication Protocols
- **paho-mqtt**: MQTT client library for IoT device communication
  - Broker: localhost:1883 (Mosquitto)
  - Topic: `waveshare/commands` (joystick input)
  - Commands: `UP`, `DOWN`, `LEFT`, `RIGHT` (quiz navigation)
  - QoS: 0 (fire-and-forget)

### Audio Systems
- **pyttsx3**: Offline text-to-speech engine
  - Fallback TTS when OpenAI unavailable
  - Voice: default system voice (macOS Samantha, Linux espeak)
  - Rate: 175 words per minute
  - Volume: 0.9 (90%)

- **pygame.mixer**: Audio playback for background music
  - Supports .wav files in `sounds/` directory
  - Crossfade transitions between tracks
  - Volume control (default 0.3 for background music)

- **OpenAI TTS-1**: Cloud-based high-quality speech synthesis
  - Voice: `nova` (clear, professional female voice)
  - Speed: 1.0 (normal rate)
  - Format: MP3 via tempfile, converted to WAV for pygame

### AI Integration
- **OpenAI GPT-4o-mini**: Quiz question generation
  - Model: `gpt-4o-mini` (fast, cost-effective)
  - Temperature: 0.7 (balanced creativity)
  - Max tokens: 150 per question
  - Prompt: Generates 4 multiple-choice options from person context

### Image Processing
- **PIL (Pillow)**: Image manipulation library
  - LANCZOS resampling for high-quality downscaling
  - ImageEnhance.Contrast for LED optimization
  - Image.quantize() for color reduction
  - ImageDraw for text rendering on matrix

- **NumPy**: Numerical computing for pixel arrays
  - RGB array manipulation (64, 64, 3)
  - Value clipping (0-255 range)
  - Type casting (uint8 for matrix driver)

### Database
- **Supabase**: PostgreSQL database + cloud storage
  - Table: `persons` (id, name, gender, context, photo_url, created_at)
  - Storage: `person-photos` bucket for profile pictures
  - API: REST API with signed URLs for photo downloads
  - Uses `src.supabase_handler.SupabaseHandler` wrapper

### Development Tools
- **dotenv**: Environment variable management
  - Loads `.env` from `config/` directory
  - Required vars: `SUPABASE_URL`, `SUPABASE_KEY`, `OPENAI_API_KEY`
- **threading**: Multi-threaded architecture for concurrent operations
- **pathlib**: Modern file path handling (cross-platform)
- **subprocess**: Shell command execution for audio conversion

---

## Hardware Requirements

### Required Components
1. **Raspberry Pi 5** (4GB+ RAM recommended)
   - Runs PioMatter RGB matrix driver
   - Handles MQTT, OpenAI API calls, audio playback
   - Requires 5V/6A power supply

2. **WaveShare RGB P3 Matrix Panel 64x64**
   - 64x64 pixel resolution (4096 total pixels)
   - HUB75 interface (16-pin ribbon cable)
   - 3mm pitch (P3) for indoor visibility
   - Dimensions: 192mm x 192mm
   - Power: 5V DC, ~4A at full brightness

3. **Power Supply**
   - 5V/6A minimum for Pi + LED matrix
   - Barrel jack connector for matrix panel
   - USB-C PD for Raspberry Pi 5

4. **MQTT Joystick Controller** (Optional, for quiz mode)
   - Arduino with joystick module
   - Publishes UP/DOWN/LEFT/RIGHT to `waveshare/commands`
   - See `Arduino/Commands_Senden_UP_RIGHT_LEFT_DOWN/` for firmware

### Wiring Diagram (Active3 Pinout)
```
HUB75 Pin → Signal → GPIO Pin (Raspberry Pi 5)
──────────────────────────────────────────────────
Pin 1/2   → R1     → GPIO 11 (Pin 23) - brown
Pin 3/4   → G1     → GPIO 27 (Pin 13) - red
Pin 5/6   → B1     → GPIO 7  (Pin 26) - orange
Pin 7/8   → 1/s    → GPIO 4  (Pin 7)  - yellow2
Pin 9/10  → R2     → GPIO 8  (Pin 24) - green
Pin 11/12 → G2     → GPIO 9  (Pin 21) - blue
Pin 13/14 → B2     → GPIO 10 (Pin 19) - purple
Pin 15/16 → A      → GPIO 22 (Pin 15) - white
Pin 17/18 → B      → GPIO 23 (Pin 16) - black
Pin 19/20 → C      → GPIO 24 (Pin 18) - brown2
Pin 21/22 → D      → GPIO 25 (Pin 22) - red2
Pin 23/24 → E      → GPIO 15 (Pin 10) - gray
Pin 25/26 → CLK    → GPIO 17 (Pin 11) - orange2
Pin 27/28 → LAT/STP → GPIO 4 (Pin 7)  - yellow2
Pin 29/30 → OE     → GPIO 18 (Pin 12) - green2
Pin 31/32 → GND    → GND     (Pin 25) - blue2

Note: Active3 uses PioMatter library with automatic pin mapping.
Pins 1, 3, 5, 7... are signal pins
Pins 2, 4, 6, 8... are GND pins
```

### Optional Components
- **HDMI Monitor**: For debugging (SSH recommended for headless)
- **Speakers**: For TTS narration and background music
- **USB Keyboard**: For manual controls if MQTT unavailable

---

## Installation

### Prerequisites
- Python 3.11+ recommended
- Raspberry Pi OS (Bookworm 64-bit)
- Internet connection for Supabase and OpenAI

### System Dependencies (Raspberry Pi)
```bash
# Update system
sudo apt-get update && sudo apt-get upgrade -y

# Install Python dependencies
sudo apt-get install -y python3-pip python3-venv python3-pil python3-numpy

# Install audio libraries
sudo apt-get install -y libportaudio2 espeak

# Install MQTT broker (optional, for local testing)
sudo apt-get install -y mosquitto mosquitto-clients
sudo systemctl enable mosquitto
sudo systemctl start mosquitto
```

### Python Environment Setup
```bash
# Navigate to project root
cd /path/to/HandsOnHCI

# Create virtual environment
python3 -m venv venv
source venv/bin/activate

# Install dependencies
pip install --upgrade pip
pip install -r requirements.txt
```

### Raspberry Pi Specific
```bash
# Install PioMatter RGB matrix driver
pip install adafruit-blinka-raspberry-pi5-piomatter

# Configure permissions for GPIO access
sudo usermod -aG gpio $USER
sudo reboot
```

---

## Configuration

### Environment Variables
Create or edit `config/.env` in project root:

```bash
# Supabase Configuration
SUPABASE_URL=https://your-project.supabase.co
SUPABASE_KEY=your-anon-public-key

# OpenAI Configuration (optional, for quiz mode)
OPENAI_API_KEY=sk-proj-your-api-key-here

# MQTT Configuration (optional, defaults shown)
MQTT_BROKER=localhost
MQTT_PORT=1883
MQTT_TOPIC=waveshare/commands
```

### Application Settings
Edit constants in `main_app.py`:

```python
# Display Settings
MATRIX_WIDTH = 64
MATRIX_HEIGHT = 64
BRIGHTNESS = 50  # 0-100, default 50 for indoor use
DISPLAY_DURATION = 5  # Seconds per person in slideshow
LANDING_DURATION = 5  # Seconds on landing screen

# Quiz Settings
QUIZ_MODE_ENABLED = True  # Set False to disable quiz
QUIZ_DISPLAY_DURATION = 15  # Seconds per quiz question
QUIZ_FREQUENCY = 5  # Show quiz every N persons

# Audio Settings
BACKGROUND_MUSIC_ENABLED = True
MUSIC_VOLUME = 0.3  # 0.0 to 1.0
TTS_VOLUME = 0.9  # 0.0 to 1.0

# MQTT Settings
MQTT_TOPIC = "waveshare/commands"
MQTT_BROKER = "localhost"
MQTT_PORT = 1883
```

### Background Music
Place `.wav` files in `waveshare/sounds/` directory:
```
waveshare/sounds/
├── Espresso.wav
├── Fortnite Festival.wav
├── Fortnite OG.wav
├── Juno.wav
└── Subway.wav
```

Files play in alphabetical order with crossfade transitions.

---

## Usage

### Basic Usage
```bash
# Activate virtual environment
source venv/bin/activate

# Run the application (on Raspberry Pi)
cd waveshare
python main_app.py
```

### Command-Line Options
Currently, `main_app.py` does not support CLI arguments. To modify behavior:
1. Edit configuration constants in `main_app.py`
2. Toggle features via environment variables
3. Use keyboard interrupt (Ctrl+C) to exit gracefully

### Operation Modes

#### 1. Normal Mode (Default)
- Shows landing screen for 5 seconds
- Displays slideshow of all persons with pixel art
- Narrates context via TTS for each person
- Shows quiz questions every 5 persons (if enabled)
- Background music plays continuously

#### 2. Quiz Mode
- Activated automatically during slideshow
- Displays multiple-choice question about person
- MQTT joystick controls:
  - **UP**: Select option A
  - **RIGHT**: Select option B
  - **DOWN**: Select option C
  - **LEFT**: Select option D
- TTS narrates question and correct answer
- Returns to slideshow after 15 seconds

#### 3. Test Mode (Manual Testing)
```bash
# Test data loader independently
cd waveshare
python data_loader.py

# Test pixel art generator with sample image
python pixel_art_generator.py /path/to/image.jpg
```

### MQTT Joystick Control

Publish commands to MQTT broker:
```bash
# Using mosquitto_pub (command line)
mosquitto_pub -h localhost -t waveshare/commands -m "UP"
mosquitto_pub -h localhost -t waveshare/commands -m "RIGHT"

# Using Arduino joystick (see Arduino/ folder)
# Upload Commands_Senden_UP_RIGHT_LEFT_DOWN.ino to Arduino
# Connects to WiFi and publishes joystick movements
```

### Graceful Shutdown
- Press **Ctrl+C** to stop the application
- Signal handler ensures clean shutdown:
  - Stops MQTT listener thread
  - Stops quiz queue thread
  - Stops background music thread
  - Clears LED matrix display

---

## Features

### 1. Dynamic Person Slideshow
- Fetches all recognized persons from Supabase database
- Downloads and caches profile photos locally
- Converts photos to 64x64 pixel art with contrast enhancement
- Displays person name as text overlay on LED matrix
- Cycles through all persons with configurable duration

### 2. Interactive Quiz Mode
- Generates multiple-choice questions using OpenAI GPT-4o-mini
- Based on person's context field from database
- 4 answer options (one correct, three plausible distractors)
- MQTT joystick navigation (UP/RIGHT/DOWN/LEFT)
- TTS narration of question and answer feedback
- Background thread pre-generates questions for smooth transitions

### 3. Text-to-Speech Narration
- **Primary**: OpenAI TTS-1 with `nova` voice (cloud-based)
- **Fallback**: pyttsx3 offline TTS (when OpenAI unavailable)
- Narrates person context during slideshow
- Reads quiz questions and answers aloud
- Adjustable speech rate and volume

### 4. Background Music System
- Plays `.wav` files from `sounds/` directory in alphabetical order
- Crossfade transitions between tracks (1-second fade)
- Volume control separate from TTS (default 30%)
- Loops through playlist continuously
- Runs in daemon thread for non-blocking playback

### 5. Landing Screen Animation
- Displays "YUNO" branding on startup
- Animated gradient background with sine wave pattern
- Custom font rendering with PIL ImageDraw
- Shows for 5 seconds before entering slideshow

### 6. Multi-threaded Architecture
- **Main thread**: Display loop (rendering frames at ~30 FPS)
- **MQTT thread**: Listens for joystick commands (non-blocking)
- **Quiz thread**: Pre-generates questions in background (queue size 3)
- **Music thread**: Manages audio playback with fade control
- Thread-safe state management with locks

### 7. Photo Caching System
- Downloads photos from Supabase Storage only once
- Caches in `waveshare/cache/photos/` directory
- Keyed by person ID: `person_{id}.jpg`
- Reduces bandwidth and speeds up slideshow
- Persistent across application restarts

### 8. Error Handling & Resilience
- Graceful degradation when OpenAI unavailable (uses pyttsx3)
- Skips persons without photos (no blank displays)
- MQTT connection retry logic with timeout
- Signal handlers for clean Ctrl+C shutdown
- Exception logging for debugging

---

## File Structure

```
waveshare/
├── main_app.py              # Main application (700+ lines)
├── data_loader.py           # Supabase data fetching & photo download
├── pixel_art_generator.py   # Image → 64x64 pixel art conversion
├── README.md                # This documentation
├── __init__.py              # Python package marker
├── cache/                   # Photo cache directory
│   └── photos/              # Cached person photos (person_{id}.jpg)
├── sounds/                  # Background music playlist
│   ├── Espresso.wav
│   ├── Fortnite Festival.wav
│   ├── Fortnite OG.wav
│   ├── Juno.wav
│   └── Subway.wav
└── simulation_output/       # Test output for debugging (unused in production)
```

### Removed Files (No Longer Used)
The following files were removed during cleanup as they are not imported by `main_app.py`:
- `config.py` - Configuration superseded by inline constants
- `joystick_listener.py` - MQTT handling moved to main_app.py
- `landing_screen.py` - Landing screen rendering inline in main_app.py
- `mqtt_client.py` - MQTT client implemented directly in main_app.py
- `quiz_mode.py` - Quiz logic integrated into main_app.py
- `slideshow.py` - Slideshow logic implemented in main_app.py
- `test_pi_*.py` - Test files no longer needed
- `aduino/` - Typo folder (Arduino firmware in root `Arduino/` instead)

---

## Related Documentation

- **Root README**: Overall project setup, Supabase configuration, environment variables
- **src/README.md**: Backend modules (face recognition, identity matching, OpenAI API)
- **frontend/README.md**: Web dashboard for person management
- **Arduino/**: Joystick firmware for MQTT control

---

## Notes

- **Raspberry Pi 5 Required**: PioMatter driver only supports Pi 5 (not compatible with Pi 4)
- **Supabase Connection**: Application will skip persons without Supabase access
- **OpenAI Optional**: Quiz mode works with pyttsx3 fallback if OpenAI key missing
- **Performance**: Rendering 64x64 pixels at 50% brightness runs smoothly at ~30 FPS
- **Power Consumption**: LED matrix at 50% brightness draws ~2A, plan power supply accordingly

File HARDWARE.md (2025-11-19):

# Hardware Setup Guide - Yuno Project

Comprehensive hardware requirements and setup instructions for the complete Yuno smart person recognition system.

---

##  Table of Contents

1. [System Overview](#system-overview)
2. [Hardware Components](#hardware-components)
3. [Raspberry Pi 1: Yuno Glasses Prototype](#raspberry-pi-1-yuno-glasses-prototype)
4. [Raspberry Pi 2: WaveShare Display Station](#raspberry-pi-2-waveshare-display-station)
5. [Arduino LCD Controller](#arduino-lcd-controller)
6. [Development System](#development-system)
7. [Network Architecture](#network-architecture)
8. [MQTT Broker Setup](#mqtt-broker-setup)
9. [Complete Wiring Guide](#complete-wiring-guide)
10. [Power Requirements](#power-requirements)
11. [Assembly Instructions](#assembly-instructions)

---

##  System Overview

The Yuno project consists of **two independent Raspberry Pi systems** that communicate via Supabase as the single source of truth:

1. **Raspberry Pi 1 (Yuno Glasses Prototype)**: Standalone wearable system with camera, microphone, Bluetooth speaker, and physical buttons for face recognition
2. **Raspberry Pi 2 (WaveShare Display)**: 64x64 RGB LED matrix display showing person slideshow and quiz mode
3. **Arduino with LCD & Joystick**: Controls the WaveShare display via MQTT (communicates only with Pi 2)
4. **Mac/PC (Development Only)**: Used for development, testing, and web frontend

**Communication Architecture:**
```
                        ┌─────────────────────┐
                        │     Supabase        │
                        │  (Single Source of  │
                        │      Truth)         │
                        │                     │
                        │  • Persons DB       │
                        │  • Photo Storage    │
                        │  • Audio Storage    │
                        └──────────┬──────────┘
                                   │
                    WiFi/Internet  │
           ┌───────────────────────┼───────────────────────┐
           │                       │                       │
           ▼                       ▼                       ▼
┌──────────────────────┐  ┌───────────────────┐  ┌──────────────────┐
│  Raspberry Pi 1      │  │  Raspberry Pi 2   │  │  Mac/PC          │
│  (Yuno Glasses)      │  │  (Display Station)│  │  (Development)   │
├──────────────────────┤  ├───────────────────┤  ├──────────────────┤
│  • Camera            │  │  • WaveShare RGB  │  │  • Face recog    │
│  • Microphone        │  │    64x64 Matrix   │  │    testing       │
│  • Bluetooth Speaker │  │  • MQTT Broker    │  │  • Frontend dev  │
│  • Normal Button     │  │  • Quiz mode      │  │  • DB management │
│  • Heartbeat Button  │  │  • TTS output     │  │                  │
│  • Face recognition  │  │  • Pixel art      │  └──────────────────┘
│  • Supabase sync     │  │  • Supabase sync  │
└──────────────────────┘  └─────────┬─────────┘
                                    │
     No direct communication    MQTT Broker
     between the two Pis         (Port 1883)
                                    │
                           ┌────────▼─────────┐
                           │  Arduino UNO R4  │
                           │  + LCD Display   │
                           │  + Joystick      │
                           │                  │
                           │  • Quiz control  │
                           │  • Person info   │
                           └──────────────────┘
```

**Key Principles:**
- **Supabase = Single Source of Truth**: Both Raspberry Pis sync data independently to/from Supabase
- **No Pi-to-Pi Communication**: The two Raspberry Pis operate independently and do not communicate directly
- **MQTT Only for Pi 2 ↔ Arduino**: Only the WaveShare display Pi communicates with Arduino via MQTT
- **Standalone Operation**: Each Pi can function without the other or the development Mac

---

## Hardware Components

### 1. Raspberry Pi 1: Yuno Glasses Prototype (Standalone Wearable)
**Purpose**: Portable face recognition system with audio interaction

**Required:**
- **Raspberry Pi 5** (4GB or 8GB RAM)
- **Camera Module**: Raspberry Pi Camera Module 3 or USB webcam
- **Microphone**: USB microphone or Raspberry Pi Audio HAT
- **Bluetooth Speaker**: Portable speaker for TTS audio output
- **Physical Buttons**:
  - Normal Button: GPIO pin for standard operation (identify mode)
  - Heartbeat Button: GPIO pin for enrollment mode
- **microSD Card**: 32GB+ (Class 10 or UHS-I)
- **Power Supply**: 5V/3A USB-C PD (portable power bank for mobile use)
- **Battery Pack** (optional): 20,000mAh USB-C power bank for portable operation

**Recommended:**
- Active cooling fan for continuous operation
- 3D-printed housing for wearable form factor
- Velcro straps or headband mount

### 2. Raspberry Pi 2: WaveShare Display Station
**Purpose**: Stationary display showing person slideshow with interactive quiz mode

**Required:**
- **Raspberry Pi 5** (4GB or 8GB RAM)
- **WaveShare RGB P3 Matrix Panel 64x64**
  - Model: 64x64 pixels, HUB75 interface
  - Pitch: 3mm (P3) for indoor visibility
  - Dimensions: 192mm x 192mm
  - Power: 5V DC, ~4A at full brightness
- **microSD Card**: 32GB+ (Class 10 or UHS-I)
- **Power Supply**: 5V/6A (27W) USB-C PD for Pi + Matrix
- **GPIO Ribbon Cable**: For HUB75 connection
- **Speakers** (optional): For TTS audio output

**Recommended:**
- Active cooling fan or heatsink for Raspberry Pi 5
- HDMI monitor for initial setup
- USB keyboard and mouse for configuration

### 3. Arduino LCD Controller (for WaveShare Display)
**Purpose**: Physical controller for WaveShare display quiz mode and person info display

**Required:**
- **Arduino UNO R4 WiFi** (with WiFiNINA support)
- **16x2 LCD Display** with I2C or parallel interface
- **Analog Joystick Module** (2-axis + button)
  - VCC: 5V
  - GND: Ground
  - VRx: X-axis analog output → A1
  - VRy: Y-axis analog output → A0
  - SW: Button digital output → Pin 7
- **Jumper Wires**: Male-to-male and male-to-female
- **Breadboard** (optional): For prototyping
- **USB Cable**: Type-B (for Arduino programming/power)

**LCD Wiring (Parallel Interface):**
- RS → Pin 12
- EN → Pin 11
- D4 → Pin 5
- D5 → Pin 4
- D6 → Pin 3
- D7 → Pin 2
- VSS → GND
- VDD → 5V
- V0 → 10kΩ potentiometer (contrast adjustment)

**Note**: Arduino only communicates with Raspberry Pi 2 (WaveShare display) via MQTT, not with Raspberry Pi 1 (Yuno Glasses).

### 4. Development System (Mac/PC)
**Purpose**: Development, testing, and web frontend access

- **Laptop or Desktop** (Mac/Windows/Linux)
- **Webcam** (optional): For testing face recognition locally
- **Minimum Specs**: 8GB RAM, Python 3.11+, 5GB free storage
- **Network**: WiFi or Ethernet connection
- **Development Tools**: Git, Python IDE (VS Code recommended), Arduino IDE

**Note**: The Mac/PC is NOT required for production operation. Both Raspberry Pis operate independently.

### 5. Network Equipment
- **WiFi Router**: 2.4GHz network (for Arduino compatibility)
- **Internet Connection**: Required for Supabase sync on both Raspberry Pis
- **Ethernet Cables** (optional): For stable Raspberry Pi connections

---

## Raspberry Pi 1: Yuno Glasses Prototype

### Hardware Assembly
1. **Install microSD Card**:
   - Flash Raspberry Pi OS Lite (64-bit, Bookworm) using Raspberry Pi Imager
   - Enable SSH in imager settings for headless setup
   - Configure WiFi credentials in imager

2. **Connect Camera**:
   - **Option A** (Raspberry Pi Camera Module): Insert ribbon cable into CSI port
   - **Option B** (USB Webcam): Plug into USB 3.0 port

3. **Connect Microphone**:
   - USB microphone: Plug into USB port
   - Test with `arecord -l` to verify detection

4. **Connect Bluetooth Speaker**:
   - Pair via `bluetoothctl`:
     ```bash
     bluetoothctl
     power on
     agent on
     default-agent
     scan on
     # Wait for speaker MAC address to appear
     pair XX:XX:XX:XX:XX:XX
     trust XX:XX:XX:XX:XX:XX
     connect XX:XX:XX:XX:XX:XX
     ```

5. **Connect Physical Buttons**:
   - **Normal Button**: Connect to GPIO 17 (Pin 11) and GND
   - **Heartbeat Button**: Connect to GPIO 27 (Pin 13) and GND
   - Use pull-up resistors (10kΩ) or enable internal pull-up in code

6. **Power Supply**:
   - For testing: 5V/3A USB-C PD adapter
   - For portable use: 20,000mAh USB-C power bank

### Software Installation (Raspberry Pi 1)
```bash
# 1. Update system
sudo apt-get update && sudo apt-get upgrade -y

# 2. Install Python dependencies
sudo apt-get install -y python3-pip python3-venv python3-opencv

# 3. Install audio libraries
sudo apt-get install -y libasound2-dev portaudio19-dev libportaudio2 \
                        libportaudiocpp0 ffmpeg libav-tools pulseaudio \
                        bluez pulseaudio-module-bluetooth

# 4. Install camera libraries
sudo apt-get install -y python3-picamera2  # For Pi Camera Module
# OR for USB webcam, no additional install needed

# 5. Enable camera interface
sudo raspi-config
# Interface Options → Camera → Enable

# 6. Clone project and install Python packages
cd ~
git clone https://github.com/Best-rbrc/HandsOnHCI.git
cd HandsOnHCI
python3 -m venv venv
source venv/bin/activate
pip install -r requirements.txt

# 7. Configure GPIO for buttons
sudo apt-get install -y python3-rpi.gpio
```

### Configuration (Raspberry Pi 1)
Create `config/.env`:
```bash
SUPABASE_URL=https://your-project.supabase.co
SUPABASE_KEY=your-anon-public-key
OPENAI_API_KEY=sk-proj-your-api-key-here

# Button GPIO pins
NORMAL_BUTTON_PIN=17
HEARTBEAT_BUTTON_PIN=27

# Audio output device (Bluetooth speaker)
AUDIO_OUTPUT_DEVICE=bluealsa
```

### Button Operation
- **Normal Button (GPIO 17)**: Press to start identify mode (recognize faces)
- **Heartbeat Button (GPIO 27)**: Press to start enrollment mode (add new person)

### Running Yuno Glasses
```bash
# Start button listener mode
cd ~/HandsOnHCI
source venv/bin/activate
python main.py button

# The system will:
# 1. Wait for button press
# 2. Capture photo on button press
# 3. Recognize face or enroll new person
# 4. Speak result via Bluetooth speaker
# 5. Sync to Supabase
# 6. Return to waiting state
```

---

## Raspberry Pi 2: WaveShare Display Station

### Hardware Assembly
1. **Install microSD Card**:
   - Flash Raspberry Pi OS (64-bit, Bookworm recommended) using Raspberry Pi Imager
   - Enable SSH in imager settings for headless setup

2. **Connect WaveShare RGB Matrix**:
   - Use GPIO header pins (see [Complete Wiring Guide](#complete-wiring-guide))
   - Connect HUB75 16-pin ribbon cable to matrix input
   - Connect 5V power to matrix barrel jack (separate from Pi power)

3. **Power Supply**:
   - Use 5V/6A power supply with USB-C PD for Raspberry Pi
   - LED matrix uses separate 5V/4A power (shared ground with Pi)

### Software Installation (Raspberry Pi 2)
```bash
# 1. Update system
sudo apt-get update && sudo apt-get upgrade -y

# 2. Install Python dependencies
sudo apt-get install -y python3-pip python3-venv python3-pil python3-numpy

# 3. Install audio libraries (for TTS)
sudo apt-get install -y libportaudio2 espeak

# 4. Install MQTT broker (Mosquitto)
sudo apt-get install -y mosquitto mosquitto-clients
sudo systemctl enable mosquitto
sudo systemctl start mosquitto

# 5. Configure Mosquitto to listen on network
sudo nano /etc/mosquitto/mosquitto.conf
# Add these lines:
listener 1883
allow_anonymous true

# Restart Mosquitto
sudo systemctl restart mosquitto

# 6. Clone project and install Python packages
cd ~
git clone https://github.com/Best-rbrc/HandsOnHCI.git
cd HandsOnHCI
python3 -m venv venv
source venv/bin/activate
pip install -r requirements.txt

# 7. Install PioMatter RGB matrix driver
pip install adafruit-blinka-raspberry-pi5-piomatter

# 8. Configure GPIO permissions
sudo usermod -aG gpio $USER
sudo reboot
```

### Configuration
Create `config/.env`:
```bash
SUPABASE_URL=https://your-project.supabase.co
SUPABASE_KEY=your-anon-public-key
OPENAI_API_KEY=sk-proj-your-api-key-here
```

### Network Setup
```bash
# Find Raspberry Pi IP address
hostname -I

# Test MQTT broker
mosquitto_sub -h localhost -t test
# In another terminal:
mosquitto_pub -h localhost -t test -m "Hello"
```

---

## Arduino LCD Controller

### Hardware Assembly
1. **Connect LCD Display** (parallel interface):
   - RS → Arduino Pin 12
   - EN → Arduino Pin 11
   - D4-D7 → Pins 5, 4, 3, 2
   - VSS → GND, VDD → 5V
   - V0 → Center pin of 10kΩ potentiometer (contrast)
   - A (backlight +) → 5V via 220Ω resistor
   - K (backlight -) → GND

2. **Connect Joystick Module**:
   - VCC → 5V
   - GND → GND
   - VRx → A1 (X-axis)
   - VRy → A0 (Y-axis)
   - SW → Pin 7 (button)

### Software Installation
1. **Install Arduino IDE**:
   - Download from [arduino.cc](https://www.arduino.cc/en/software)
   - Install **WiFiNINA** library (Tools → Manage Libraries)
   - Install **PubSubClient** library (for MQTT)
   - Install **LiquidCrystal** library (built-in)

2. **Upload Firmware**:
   ```bash
   # Open Arduino IDE
   # File → Open → Arduino/Commands_Senden_UP_RIGHT_LEFT_DOWN.ino
   # Select Board: Arduino UNO R4 WiFi
   # Select Port: (your Arduino COM port)
   # Click Upload
   ```

3. **Configure WiFi & MQTT**:
   Edit in `.ino` file:
   ```cpp
   const char* WIFI_SSID     = "YourWiFiName";
   const char* WIFI_PASSWORD = "YourWiFiPassword";
   const char* MQTT_HOST     = "192.168.1.XXX";  // Raspberry Pi 2 IP (WaveShare display)
   const uint16_t MQTT_PORT  = 1883;
   ```
   
   **Important**: Set MQTT_HOST to the IP address of **Raspberry Pi 2** (WaveShare display), NOT Raspberry Pi 1 (Yuno Glasses).

### Testing
```bash
# On Raspberry Pi 2 (WaveShare display), subscribe to Arduino topic:
mosquitto_sub -h localhost -t arduino/to/pi

# Move joystick on Arduino
# Should see: JOY:UP, JOY:DOWN, JOY:LEFT, JOY:RIGHT

# Publish command to Arduino:
mosquitto_pub -h localhost -t pi/to/arduino -m "NAME:John Doe"
mosquitto_pub -h localhost -t pi/to/arduino -m "DESC:Computer Science Student"
# LCD should display the text
```

---

## Development System (Mac/PC)

### Purpose
The Mac/PC is used **only for development and testing**. It is NOT required for production operation.

### Setup
1. **Clone Repository**:
   ```bash
   git clone https://github.com/Best-rbrc/HandsOnHCI.git
   cd HandsOnHCI
   ```

2. **Create Virtual Environment**:
   ```bash
   python3 -m venv venv
   source venv/bin/activate  # macOS/Linux
   # .\venv\Scripts\activate  # Windows
   ```

3. **Install Dependencies**:
   ```bash
   pip install -r requirements.txt
   ```

4. **Configure Environment**:
   Create `config/.env`:
   ```bash
   SUPABASE_URL=https://your-project.supabase.co
   SUPABASE_KEY=your-anon-public-key
   OPENAI_API_KEY=sk-proj-your-api-key-here
   ```

### Development Use Cases
- **Test Face Recognition**: `python main.py identify` (uses Mac webcam)
- **Enroll Test Persons**: `python main.py enroll`
- **Database Management**: `python main.py sync`
- **Frontend Development**: Open `frontend/index.html` in browser
- **Test Components**: Run scripts in `tests/` directory

### Web Frontend Access
```bash
# Open frontend in browser (file:// protocol)
open frontend/index.html  # macOS
start frontend/index.html  # Windows

# OR serve with Python HTTP server
cd frontend
python3 -m http.server 8000
# Open http://localhost:8000
```

---

## WaveShare RGB Matrix Wiring

### GPIO Wiring (Active3 Pinout)
Connect Raspberry Pi 5 GPIO to WaveShare HUB75 connector:

| HUB75 Pin | Signal  | Raspberry Pi GPIO | Physical Pin | Wire Color |
|---|---|---|---|---|
| 1/2 | R1 | GPIO 11 | Pin 23 | Brown |
| 3/4 | G1 | GPIO 27 | Pin 13 | Red |
| 5/6 | B1 | GPIO 7 | Pin 26 | Orange |
| 7/8 | 1/s | GPIO 4 | Pin 7 | Yellow2 |
| 9/10 | R2 | GPIO 8 | Pin 24 | Green |
| 11/12 | G2 | GPIO 9 | Pin 21 | Blue |
| 13/14 | B2 | GPIO 10 | Pin 19 | Purple |
| 15/16 | A | GPIO 22 | Pin 15 | White |
| 17/18 | B | GPIO 23 | Pin 16 | Black |
| 19/20 | C | GPIO 24 | Pin 18 | Brown2 |
| 21/22 | D | GPIO 25 | Pin 22 | Red2 |
| 23/24 | E | GPIO 15 | Pin 10 | Gray |
| 25/26 | CLK | GPIO 17 | Pin 11 | Orange2 |
| 27/28 | LAT/STP | GPIO 4 | Pin 7 | Yellow2 |
| 29/30 | OE | GPIO 18 | Pin 12 | Green2 |
| 31/32 | GND | GND | Pin 25 | Blue2 |

**Notes:**
- Odd-numbered HUB75 pins (1, 3, 5...) are signal pins
- Even-numbered HUB75 pins (2, 4, 6...) are ground pins
- Connect all grounds together (Pi GND + Matrix GND)
- PioMatter library handles pin mapping automatically

### Power Connection
- **LED Matrix**: 5V/4A via barrel jack connector (separate PSU)
- **Raspberry Pi**: 5V/3A via USB-C (can use same PSU with splitter if 6A+)
- **Ground**: Connect Pi GND to Matrix GND for common reference

### Testing WaveShare Display
```bash
# Run WaveShare display application on Raspberry Pi 2
cd ~/HandsOnHCI/waveshare
source ../venv/bin/activate
python main_app.py

# Should display:
# 1. Landing screen with "YUNO" branding (5 seconds)
# 2. Slideshow of all persons from Supabase database
# 3. Quiz questions with MQTT joystick control
```

---

## Network Architecture

### Network Topology
```
                    Internet (Supabase Cloud)
                            │
                            │ HTTPS (443)
                            │
                    ┌───────┴────────┐
                    │                │
                    ▼                ▼
         ┌──────────────────┐  ┌──────────────────┐
         │  Raspberry Pi 1  │  │  Raspberry Pi 2  │
         │  (Yuno Glasses)  │  │  (WaveShare)     │
         │  192.168.1.150   │  │  192.168.1.151   │
         │                  │  │                  │
         │  • Supabase sync │  │  • Supabase sync │
         │  • No MQTT       │  │  • MQTT Broker   │
         └──────────────────┘  └────────┬─────────┘
                                        │
              No communication      MQTT (1883)
              between the two Pis      │
                                       ▼
                              ┌──────────────────┐
                              │  Arduino UNO R4  │
                              │  192.168.1.200   │
                              │                  │
                              │  • MQTT Client   │
                              └──────────────────┘

         ┌──────────────────┐
         │  Mac/PC (Dev)    │  ← Development only
         │  192.168.1.100   │  ← Not required for
         │                  │     production
         │  • Testing       │
         │  • Frontend dev  │
         └──────────────────┘
```

### Communication Flows
1. **Raspberry Pi 1 ↔ Supabase**: WiFi/Internet → HTTPS (enrolls persons, syncs data)
2. **Raspberry Pi 2 ↔ Supabase**: WiFi/Internet → HTTPS (fetches persons for display)
3. **Raspberry Pi 2 ↔ Arduino**: Local Network → MQTT (quiz control, person info)
4. **Mac/PC ↔ Supabase**: Development/testing only (optional)

**Important**: The two Raspberry Pis **do not communicate directly**. They only sync via Supabase as the single source of truth.

### Port Configuration
- **MQTT Broker** (Raspberry Pi 2 only): Port 1883 (unencrypted, local network)
- **Supabase** (Both Raspberry Pis): HTTPS Port 443 (outbound to internet)
- **SSH** (Both Raspberry Pis): Port 22 (for remote access/debugging)
- **Web Frontend** (Mac/PC dev): Port 8000 (Python HTTP server, optional)

### Firewall Rules (Raspberry Pi 2 - WaveShare Display)
```bash
# Allow MQTT from local network (for Arduino)
sudo ufw allow from 192.168.1.0/24 to any port 1883

# Allow SSH
sudo ufw allow 22

# Allow outbound HTTPS for Supabase
sudo ufw allow out 443

# Enable firewall
sudo ufw enable
```

### Firewall Rules (Raspberry Pi 1 - Yuno Glasses)
```bash
# Allow SSH
sudo ufw allow 22

# Allow outbound HTTPS for Supabase
sudo ufw allow out 443

# Enable firewall
sudo ufw enable

# Note: No MQTT ports needed on Pi 1
```

---

## MQTT Broker Setup

### Installation (on Raspberry Pi 2 - WaveShare Display ONLY)

**Important**: MQTT broker is only installed on Raspberry Pi 2 (WaveShare display). Raspberry Pi 1 (Yuno Glasses) does NOT use MQTT.

```bash
# Install Mosquitto on Raspberry Pi 2
sudo apt-get install -y mosquitto mosquitto-clients

# Configure Mosquitto
sudo nano /etc/mosquitto/mosquitto.conf
```

Add configuration:
```conf
# Listen on all interfaces
listener 1883 0.0.0.0

# Allow anonymous connections (local network only)
allow_anonymous true

# Logging
log_dest file /var/log/mosquitto/mosquitto.log
log_type all

# Persistence
persistence true
persistence_location /var/lib/mosquitto/
```

Restart service:
```bash
sudo systemctl restart mosquitto
sudo systemctl enable mosquitto
```

### MQTT Topics
| Topic | Publisher | Subscriber | Message Format | Purpose |
|---|---|---|---|---|
| `arduino/to/pi`  | Arduino | Raspberry Pi 2 (WaveShare) | `JOY:UP/DOWN/...` | Joystick commands |
| `pi/to/arduino`  | Raspberry Pi 2  | Arduino | `NAME:...`/`DESC:`  | Person info for LCD |
| `waveshare/commands` | Arduino | Raspberry Pi 2 (WaveShare) | `UP/DOWN/LEFT/...`  | Quiz navigation |

**Note**: Raspberry Pi 1 (Yuno Glasses) does NOT publish or subscribe to any MQTT topics.

### Testing MQTT (on Raspberry Pi 2 only)
```bash
# Subscribe to all topics (debug)
mosquitto_sub -h localhost -t '#' -v

# Test Arduino → Pi 2
mosquitto_pub -h localhost -t arduino/to/pi -m "JOY:UP"

# Test Pi 2 → Arduino
mosquitto_pub -h localhost -t pi/to/arduino -m "NAME:Test User"
mosquitto_pub -h localhost -t pi/to/arduino -m "DESC:This is a test"
```

---

## Complete Wiring Guide

### Raspberry Pi 1 (Yuno Glasses) GPIO Connections
```
Camera Module:
  - Ribbon cable → CSI port (camera connector)
  OR USB webcam → USB 3.0 port

Microphone:
  - USB microphone → USB port

Bluetooth Speaker:
  - Paired via Bluetooth (no physical connection)

Normal Button:
  - One side → GPIO 17 (Pin 11)
  - Other side → GND (Pin 9)
  - Internal pull-up enabled in software

Heartbeat Button:
  - One side → GPIO 27 (Pin 13)
  - Other side → GND (Pin 14)
  - Internal pull-up enabled in software

Power:
  - USB-C → 5V/3A power adapter or power bank
```

### Raspberry Pi 2 (WaveShare Display) GPIO Pinout (40-pin Header)
```
        3V3  (1) (2)  5V
   GPIO2/SDA (3) (4)  5V
   GPIO3/SCL (5) (6)  GND
      GPIO4  (7) (8)  GPIO14/TXD
        GND  (9) (10) GPIO15/RXD
     GPIO17 (11) (12) GPIO18
     GPIO27 (13) (14) GND
     GPIO22 (15) (16) GPIO23
        3V3 (17) (18) GPIO24
     GPIO10 (19) (20) GND
      GPIO9 (21) (22) GPIO25
     GPIO11 (23) (24) GPIO8
        GND (25) (26) GPIO7
```

### Arduino UNO R4 WiFi Connections
```
Power:
  5V  → Joystick VCC, LCD VDD
  GND → Joystick GND, LCD VSS/K

Digital Pins:
  Pin 2  → LCD D7
  Pin 3  → LCD D6
  Pin 4  → LCD D5
  Pin 5  → LCD D4
  Pin 7  → Joystick SW (button)
  Pin 11 → LCD EN (enable)
  Pin 12 → LCD RS (register select)

Analog Pins:
  A0 → Joystick VRy (Y-axis)
  A1 → Joystick VRx (X-axis)
```

### Power Distribution

**Raspberry Pi 1 (Yuno Glasses):**
```
Power Bank or USB-C Adapter (5V/3A)
   │
   └─── USB-C → Raspberry Pi 1 (3A)
         │
         ├─── USB Microphone (powered by Pi)
         └─── USB Camera (if used, powered by Pi)

Bluetooth Speaker: Independent battery
```

**Raspberry Pi 2 (WaveShare Display):**
```
Main Power Supply (5V/6A)
   │
   ├─── USB-C → Raspberry Pi 2 (3A)
   │
   └─── Barrel Jack → WaveShare LED Matrix (4A)
         │
         └─── GND connected to Pi GND (common ground)
```

**Arduino:**
```
Separate:
   USB-B → Arduino UNO R4 (500mA from PC/USB adapter)
```

---

## Power Requirements

### Component Power Draw
| Component | Voltage | Current | Power  | Notes |
|---|---|---|---|---|
| Raspberry Pi 1 (Yuno Glasses)| 5V | 3A | 15W | USB-C PD, portable |
| Raspberry Pi 2 (WaveShare) | 5V | 3A | 15W | USB-C PD, stationary |
| WaveShare LED Matrix | 5V | 4A | 20W | At full brightness (100%) |
| WaveShare @ 50% | 5V | ~2A | 10W | Typical usage |
| Arduino UNO R4 WiFi | 5V | 500mA | 2.5W | Via USB or barrel jack |
| USB Microphone | 5V | 100mA | 0.5W | Powered by Pi 1 |
| USB Webcam | 5V | 500mA | 2.5W | Powered by Pi 1 (if used) |
| Bluetooth Speaker | 3.7V | Varies  | N/A | Independent battery |

### Recommended Power Supplies

**Raspberry Pi 1 (Yuno Glasses) - Portable:**
- **Development/Testing**: Official 27W USB-C Power Supply
- **Portable Use**: 20,000mAh USB-C power bank (provides ~4 hours runtime)
- **Recommended**: Anker PowerCore 20100 or similar USB-C PD power bank

**Raspberry Pi 2 (WaveShare Display) - Stationary:**
- **Option 1** (Separate):
  - Raspberry Pi: Official 27W USB-C Power Supply
  - LED Matrix: 5V/5A switching power supply with barrel jack
  - Arduino: USB power from PC or 5V/1A wall adapter

- **Option 2** (Single PSU):
  - 5V/10A (50W) switching power supply
  - Split to USB-C for Pi (via PD trigger) and barrel jack for matrix
  - Arduino powered separately via USB

### Power Safety
- ⚠️ **Never connect 5V directly to GPIO pins** (use only for VCC pins)
- ✅ **Common ground required** between Pi and LED matrix
- ⚠️ **Avoid USB hub power** for Raspberry Pi (may be unstable)
- ✅ **Use ferrite cores** on power cables to reduce EMI

---

## Assembly Instructions

### Step 1: Raspberry Pi 1 (Yuno Glasses) Assembly
1. Flash Raspberry Pi OS Lite to microSD card
2. Insert microSD into Pi 1
3. Connect camera module or USB webcam
4. Connect USB microphone
5. Pair Bluetooth speaker via `bluetoothctl`
6. Connect Normal Button to GPIO 17 and GND
7. Connect Heartbeat Button to GPIO 27 and GND
8. Power on and complete OS setup
9. Enable SSH and configure WiFi
10. Update system: `sudo apt-get update && sudo apt-get upgrade`
11. Install software (see [Raspberry Pi 1 Setup](#raspberry-pi-1-yuno-glasses-prototype))
12. Configure `.env` with Supabase credentials
13. Test button functionality: `python main.py button`

### Step 2: Raspberry Pi 2 (WaveShare Display) Assembly
1. Flash Raspberry Pi OS to microSD card
2. Insert microSD into Pi 2
3. Connect HDMI monitor, keyboard, mouse (for initial setup)
4. Power on and complete OS setup
5. Enable SSH and configure WiFi
6. Update system: `sudo apt-get update && sudo apt-get upgrade`
7. Install MQTT Broker (see [MQTT Broker Setup](#mqtt-broker-setup))
8. Configure to listen on network (0.0.0.0:1883)
9. Note Raspberry Pi 2 IP address: `hostname -I`
10. Power off Pi 2
11. Connect WaveShare RGB Matrix (see wiring guide)
12. Power on and install software (see [Raspberry Pi 2 Setup](#raspberry-pi-2-waveshare-display-station))
13. Configure `.env` with Supabase credentials
14. Test display: `cd waveshare && python main_app.py`

### Step 3: Arduino Assembly
1. Connect LCD display to Arduino (pins 2-5, 11-12)
2. Connect joystick module (A0, A1, Pin 7)
3. Adjust LCD contrast with potentiometer
4. Upload firmware from `Arduino/Commands_Senden_UP_RIGHT_LEFT_DOWN/`
5. Configure WiFi SSID/password and MQTT broker IP (**Raspberry Pi 2 IP**)
6. Test: Joystick movements should send MQTT messages to Pi 2

### Step 4: System Integration Test
1. **Raspberry Pi 1 (Yuno Glasses)**:
   - Press Normal Button → should capture and identify face
   - Press Heartbeat Button → should start enrollment mode
   - Verify TTS output via Bluetooth speaker
   - Check Supabase for synced person data

2. **Raspberry Pi 2 (WaveShare Display)**:
   - Start MQTT broker: `sudo systemctl start mosquitto`
   - Run WaveShare app: `cd waveshare && python main_app.py`
   - Verify landing screen appears
   - Verify persons from Supabase appear in slideshow

3. **Arduino → Raspberry Pi 2 (MQTT)**:
   - Power on Arduino (should connect to WiFi and MQTT)
   - Move joystick → should see MQTT messages in Pi 2 terminal
   - Quiz mode should respond to joystick input
   - LCD should display person name/info

4. **End-to-End Test**:
   - Enroll new person on Raspberry Pi 1 (Heartbeat button)
   - Wait for Supabase sync (~30 seconds)
   - Verify new person appears on WaveShare display (Pi 2)
   - Both Pis operate independently via Supabase

### Step 5: Development System Setup (Optional)
1. On Mac/PC: Clone repository, create venv, install requirements
2. Configure `config/.env` with API keys
3. Test camera: `python main.py identify`
4. Enroll test person: `python main.py enroll`
5. Sync to Supabase: `python main.py sync`
6. Open frontend: `open frontend/index.html`
7. Verify persons appear in web dashboard

---

## Troubleshooting

### Raspberry Pi 1 (Yuno Glasses) Issues
- **Camera not detected**: Run `vcgencmd get_camera` or check `lsusb` for USB webcam
- **Button not responding**: Verify GPIO wiring, test with `gpio readall`
- **Bluetooth speaker connection lost**: Re-pair with `bluetoothctl connect MAC_ADDRESS`
- **Supabase sync failed**: Check internet connection, verify API keys in `.env`
- **TTS not working**: Test audio output with `speaker-test`, check Bluetooth connection

### Raspberry Pi 2 (WaveShare Display) Issues
- **No display on LED matrix**: Check power supply, verify GPIO connections
- **MQTT not accessible**: Check firewall, ensure Mosquitto listening on 0.0.0.0
- **GPIO permission denied**: Run `sudo usermod -aG gpio $USER` and reboot
- **Persons not appearing**: Verify Supabase connection, check data loader logs
- **Quiz mode not working**: Test MQTT with `mosquitto_sub -t '#'`

### Arduino Issues
- **WiFi connection failed**: Check SSID/password, ensure 2.4GHz network
- **MQTT not connecting**: Verify Raspberry Pi 2 IP (not Pi 1!), test with `ping`
- **LCD contrast too dark/light**: Adjust potentiometer on V0 pin
- **Joystick not responding**: Check analog pin connections (A0, A1)

### Network Issues
- **Arduino can't reach MQTT**: Ensure Arduino connected to same WiFi as Pi 2
- **MQTT timeout**: Check firewall rules on Raspberry Pi 2
- **Supabase connection failed**: Verify internet access, check API keys
- **Pi 1 and Pi 2 not syncing**: Check Supabase connection on BOTH Pis independently

### Data Sync Issues
- **Person enrolled on Pi 1 not appearing on Pi 2**: 
  - Check Supabase dashboard to verify person exists
  - Verify photo uploaded to Supabase Storage
  - Check Pi 2 data loader logs for sync errors
  - Wait up to 60 seconds for automatic refresh

---

## Notes

- **Raspberry Pi 5 Required**: PioMatter driver only supports Pi 5 (not compatible with Pi 4)
- **Two Independent Systems**: Pi 1 (Yuno Glasses) and Pi 2 (WaveShare) operate independently
- **Supabase as Single Source of Truth**: Both Pis sync to Supabase, no direct Pi-to-Pi communication
- **MQTT Only on Pi 2**: Only Raspberry Pi 2 runs MQTT broker (for Arduino communication)
- **Arduino R4 WiFi**: Older Arduino boards require separate WiFi shield
- **Power Consumption**: LED matrix at 50% brightness = optimal balance (bright + efficient)
- **Cooling**: Raspberry Pi 5 runs hot under load, active cooling recommended for both Pis
- **Cable Management**: Use cable ties to organize GPIO ribbon cables
- **Portable Operation**: Pi 1 can run on power bank for ~4 hours with 20,000mAh battery
- **Development Optional**: Mac/PC development system NOT required for production operation

---

## Related Documentation

- **Main README.md**: Software setup, Python environment, database configuration
- **src/README.md**: Face recognition backend, OpenAI integration, button handler
- **frontend/README.md**: Web dashboard for person management
- **waveshare/README.md**: RGB LED matrix display system details (Pi 2)
- **Arduino firmware**: `Arduino/Commands_Senden_UP_RIGHT_LEFT_DOWN/`

---

## System Comparison

| Feature | Raspberry Pi 1 (Yuno Glasses) | Raspberry Pi 2 (WaveShare Display) | Mac/PC (Development) |
|---|---|---|---|
| **Purpose** | Portable face recognition | Stationary display & quiz mode | Development & testing|
| **Camera** | ✅ Yes (Pi Camera or USB) | ❌ No | ✅ Optional (for testing) |
| **Microphone** | ✅ Yes (USB) | ❌ No | ✅ Optional |
| **Audio Output** | ✅ Bluetooth speaker | ✅ Optional (TTS via speakers) | ✅ Built-in speakers |
| **Physical Buttons** | ✅ 2 buttons (GPIO 17, 27) | ❌ No | ❌ No |
| **WaveShare Display** | ❌ No | ✅ Yes (64x64 RGB matrix) | ❌ No |
| **MQTT Broker** | ❌ No | ✅ Yes (for Arduino) | ❌ No |
| **MQTT Client** | ❌ No | ✅ Yes (receives from Arduino) | ❌ No |
| **Supabase Sync** | ✅ Yes (enrolls & syncs) | ✅ Yes (fetches persons) | ✅ Optional |
| **Face Recognition** | ✅ Yes (ArcFace ONNX) | ❌ No | ✅ Yes (testing) |
| **Quiz Mode** | ❌ No | ✅ Yes (OpenAI + joystick) | ❌ No |
| **Power Source** | Portable (power bank) | Stationary (AC adapter) | AC adapter |
| **Operation Mode** | Standalone (no Mac needed) | Standalone (no Mac needed) | Development only |
| **Communication** | Supabase only | Supabase + MQTT (Arduino) | Supabase only |

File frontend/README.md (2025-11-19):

# frontend/ – Web Interface for Yuno

This folder contains the web-based user interface for viewing, managing, and interacting with the person database. The frontend provides an elegant, modern interface for browsing enrolled persons, viewing their context, and managing their information.

---

## Table of Contents

1. [Overview](#overview)
2. [Technology Stack](#technology-stack)
3. [File Structure](#file-structure)
4. [Features](#features)
5. [Architecture](#architecture)
6. [Setup & Configuration](#setup--configuration)
7. [Supabase Integration](#supabase-integration)
8. [UI/UX Design](#uiux-design)
9. [API Integration](#api-integration)
---

## Overview

The Yuno frontend is a **single-page application (SPA)** built with vanilla JavaScript and modern CSS. It connects directly to Supabase to fetch person data and display it in an interactive, card-based interface. The application features a beautiful landing page, animated dashboard, and detailed person modals with full CRUD capabilities.

**Key Characteristics**:
- **Zero build process**: Pure HTML, CSS, and JavaScript
- **Framework-free**: No React, Vue, or Angular - just vanilla JS
- **Supabase-powered**: Direct database and storage integration
- **Responsive design**: Works on mobile, tablet, and desktop
- **Modern aesthetics**: Gradient backgrounds, smooth animations, glassmorphism effects

---

## Technology Stack

### Core Technologies

#### **HTML5**
- Single `index.html` file containing the entire application
- Semantic HTML structure
- SEO-friendly meta tags
- Accessibility considerations

#### **CSS3**
- **Modern Features**:
  - CSS Grid for responsive layouts
  - Flexbox for component alignment
  - CSS Variables for theming (could be added)
  - Animations and transitions
  - Backdrop filters (glassmorphism)
  - Custom scrollbar styling
  
- **Design Techniques**:
  - Gradient backgrounds
  - Card-based layouts
  - Modal overlays
  - Hover effects and micro-interactions
  - Responsive breakpoints

#### **Vanilla JavaScript (ES6+)**
- **Modern JS Features**:
  - Async/await for asynchronous operations
  - Arrow functions
  - Template literals
  - Destructuring
  - Array methods (map, filter, reduce)
  - Promise-based API calls

- **DOM Manipulation**:
  - Direct element creation and updates
  - Event listeners
  - Dynamic content injection
  - State management (via global variables)

### External Libraries

#### **Supabase JavaScript Client (`@supabase/supabase-js@2`)**
- **CDN-loaded**: `https://cdn.jsdelivr.net/npm/@supabase/supabase-js@2`
- **Features Used**:
  - Database queries (SELECT, UPDATE, DELETE)
  - Storage operations (createSignedUrl, download)
  - Client initialization with anon key
  - Real-time subscriptions (could be added)

**Why Supabase?**
- PostgreSQL database with REST API
- Built-in authentication (not yet used)
- File storage with access control
- Real-time capabilities
- Row Level Security (RLS)

---

## File Structure

```
frontend/
├── index.html              # Main application file (all-in-one)
├── SUPABASE_SETUP.md      # Storage bucket configuration guide
└── README.md              # This file
```

## Features

### Landing Page

**Visual Design**:
- Full-screen gradient background (purple to pink)
- Large "YUNO" logo with glow effect
- Tagline: "Smart Person Recognition & Database"
- Animated "Enter Dashboard" button
- Pulsing radial gradients
- Fade-in animations

**Interactions**:
- Single button to enter the dashboard
- Smooth transition to dashboard (fade out effect)

**CSS Effects**:
- `@keyframes pulse`: Pulsing background gradients
- `@keyframes fadeInUp`: Entrance animation
- `@keyframes glow`: Logo glow effect
- Glassmorphism button with hover effects

---

### Dashboard

**Layout**:
- **Header Section**:
  - "Your People" title with gradient text
  - Subtitle with usage instructions
  - Statistics cards (total persons, total memories)
  - Decorative pulsing gradient orb
  
- **Grid Section**:
  - Responsive grid layout (1-3 columns based on screen size)
  - Person cards with hover effects
  - Loading spinner during data fetch
  - Error messages for failed operations

**Statistics**:
- **Total Persons**: Count of enrolled people
- **Total Memories**: Count of persons with context
- **Animated Counters**: Numbers count up from 0 on load

**Responsive Design**:
- Desktop: 3 columns (1400px max width)
- Tablet: 2 columns
- Mobile: 1 column

---

### Person Cards

**Card Structure**:
- **Image Section**: 300px height container
  - Profile photo (or placeholder)
  - Hover zoom effect on image
  
- **Content Section**:
  - Person name (bold, large font)
  - Person ID (smaller, gray text)
  - Context preview (3-line clamp with ellipsis)

**Visual Effects**:
- Border glow on hover
- Elevation increase (translateY + scale)
- Gradient overlay fade-in
- Shadow enhancement
- Smooth 300ms transitions

**Interactions**:
- Click to open detailed modal
- Entire card is clickable

---

###  Person Details Modal

**Structure**:

1. **Header**:
   - Circular profile photo (150px, bordered)
   - Person name (gradient text)
   - Person ID and creation date
   - Close button (top-right)

2. **Body**:
   - **View Mode**:
     - "Context & Information" section
     - Formatted context entries with timestamps
     - Labeled sections (Analyse, Transkript, etc.)
     - Structured display with entry cards
   
   - **Edit Mode**:
     - Name input field
     - Context textarea (expandable)
     - Form validation
   
   - **Delete Confirmation Mode**:
     - Warning message
     - Confirm/Cancel buttons
     - Styled alert box

3. **Footer Actions**:
   - **View Mode**: Edit, Delete buttons
   - **Edit Mode**: Save, Cancel buttons
   - **Delete Mode**: Yes Delete, Cancel buttons

**Features**:
- **Context Parsing**: Intelligently formats context into labeled entries
- **Timestamp Display**: Shows when each context entry was added
- **Multi-line Context**: Preserves newlines and formatting
- **Responsive**: Adapts to mobile screens
- **Keyboard Support**: Close with Escape key
- **Click Outside**: Close by clicking overlay

**Modal Interactions**:
```javascript
openModal(person)      // Open with person data
closeModal()           // Close modal
toggleEdit()           // Switch to edit mode
savePerson()           // Update database
showDeleteConfirmation() // Show delete prompt
confirmDelete()        // Execute deletion
```

---

### CRUD Operations

#### **Create** (Not in Frontend)
- Person creation handled by backend (enroll pipeline)
- Frontend is read-only for new persons

#### **Read**
```javascript
async function fetchPersons() {
  const { data: persons, error } = await supabase
    .from('persons')
    .select('*');
  
  // Process and display persons
}
```

**Process**:
1. Query Supabase `persons` table
2. Fetch all columns (`SELECT *`)
3. Generate signed URLs for images
4. Render person cards
5. Update statistics

#### **Update**
```javascript
async function savePerson() {
  const { data, error } = await supabase
    .from('persons')
    .update({
      name: newName,
      context: newContext
    })
    .eq('id', currentPersonData.id)
    .select();
  
  // Refresh UI
}
```

**Process**:
1. Validate input (name not empty)
2. Update Supabase record
3. Update local state
4. Refresh dashboard grid
5. Show success message

#### **Delete**
```javascript
async function confirmDelete() {
  const { error } = await supabase
    .from('persons')
    .delete()
    .eq('id', currentPersonData.id);
  
  // Refresh UI
}
```

**Process**:
1. Show confirmation dialog
2. Execute DELETE query on confirmation
3. Close modal
4. Remove card from grid
5. Update statistics
6. Show success message

---

## Architecture

### Application Flow

```
┌─────────────────────────────────────────────────────────────┐
│                        Landing Page                          │
│  ┌──────────────────────────────────────────────────────┐  │
│  │  "YUNO" Logo + "Enter Dashboard" Button               │  │
│  └────────────────────────┬─────────────────────────────┘  │
└────────────────────────────┼────────────────────────────────┘
                             │ Click
                             ▼
┌─────────────────────────────────────────────────────────────┐
│                          Dashboard                           │
│  ┌──────────────────────────────────────────────────────┐  │
│  │  Header: Title, Subtitle, Stats                       │  │
│  ├──────────────────────────────────────────────────────┤  │
│  │  Loading State → Fetch from Supabase                 │  │
│  ├──────────────────────────────────────────────────────┤  │
│  │  Person Cards Grid (Generated Dynamically)            │  │
│  │  ┌────────┐  ┌────────┐  ┌────────┐                 │  │
│  │  │ Card 1 │  │ Card 2 │  │ Card 3 │                 │  │
│  │  └───┬────┘  └────────┘  └────────┘                 │  │
│  └──────┼───────────────────────────────────────────────┘  │
└─────────┼──────────────────────────────────────────────────┘
          │ Click Card
          ▼
┌─────────────────────────────────────────────────────────────┐
│                      Person Details Modal                     │
│  ┌──────────────────────────────────────────────────────┐  │
│  │  Photo + Name + ID + Created Date                     │  │
│  ├──────────────────────────────────────────────────────┤  │
│  │  ┌─ View Mode ─────────────────────────────────────┐ │  │
│  │  │  Context Entries (formatted with timestamps)     │ │  │
│  │  │  [Edit] [Delete]                                 │ │  │
│  │  └──────────────────────────────────────────────────┘ │  │
│  │                        OR                              │  │
│  │  ┌─ Edit Mode ─────────────────────────────────────┐ │  │
│  │  │  Name Input                                       │ │  │
│  │  │  Context Textarea                                 │ │  │
│  │  │  [Save] [Cancel]                                  │ │  │
│  │  └──────────────────────────────────────────────────┘ │  │
│  │                        OR                              │  │
│  │  ┌─ Delete Confirmation ───────────────────────────┐ │  │
│  │  │  "Are you sure?"                                  │ │  │
│  │  │  [Yes, Delete] [Cancel]                           │ │  │
│  │  └──────────────────────────────────────────────────┘ │  │
│  └──────────────────────────────────────────────────────┘  │
└─────────────────────────────────────────────────────────────┘
```

### Data Flow

```
Frontend                    Supabase                  Backend
   │                           │                         │
   ├─ Initial Load ───────────►│                         │
   │                           │                         │
   │◄─ Fetch Persons ──────────┤                         │
   │   (SELECT * FROM persons) │                         │
   │                           │                         │
   ├─ Get Image URLs ─────────►│                         │
   │   (createSignedUrl)       │                         │
   │                           │                         │
   │◄─ Signed URLs ────────────┤                         │
   │                           │                         │
   │                           │                         │
   ├─ User Updates Person ────►│                         │
   │   (UPDATE persons)        │                         │
   │                           │                         │
   │◄─ Success ────────────────┤                         │
   │                           │                         │
   │                           │                         │
   │                           │   Backend writes to DB  │
   │                           │◄────────────────────────┤
   │                           │   (sync_manager.py)     │
   │                           │                         │
   ├─ Periodic Refresh ───────►│                         │
   │   (re-fetch persons)      │                         │
   │                           │                         │
```

### State Management

**Global Variables**:
```javascript
const supabase = window.supabase.createClient(URL, KEY);
let currentPersonData = null; // Currently selected person in modal
```

**Component State**:
- Landing page visibility: DOM manipulation (`display: none/block`)
- Dashboard visibility: CSS class (`active`)
- Modal state: CSS class (`active`)
- Edit mode: Form visibility toggles
- Delete confirmation: Element visibility toggles

**No Framework State Management**:
- Direct DOM manipulation
- Event-driven updates
- No virtual DOM or reactive state

---

## Setup & Configuration

### Prerequisites

1. **Supabase Project**:
   - Active Supabase account
   - Project created with `persons` table
   - Storage buckets configured

2. **Web Server** (for local testing):
   - Python: `python -m http.server 8000`
   - Node.js: `npx serve`
   - VS Code: Live Server extension

### Configuration Steps

#### 1. Update Supabase Credentials

**Location**: `index.html` (inside `<script>` tag)

```javascript
// Configuration
const SUPABASE_URL = 'https://YOUR-PROJECT.supabase.co';
const SUPABASE_ANON_KEY = 'eyJhbGc...YOUR_ANON_KEY';
```

**How to Get Credentials**:
1. Go to Supabase Dashboard
2. Select your project
3. Navigate to **Settings** → **API**
4. Copy:
   - **Project URL** → `SUPABASE_URL`
   - **anon/public key** → `SUPABASE_ANON_KEY`

#### 2. Configure Storage Buckets

**Required Buckets**:
- `persons-photos`: For profile images
- `persons-audio` (optional): For audio recordings

**Configuration**:
See `SUPABASE_SETUP.md` for detailed instructions on:
- Creating buckets
- Setting privacy levels
- Configuring RLS policies
- Generating signed URLs

**Quick Setup**:
```sql
-- Create storage buckets (via Supabase Dashboard → Storage)
-- Bucket name: persons-photos
-- Public: No (private)

-- Create RLS policy for anon access
CREATE POLICY "Allow anon to read photos"
ON storage.objects FOR SELECT
TO anon
USING (bucket_id = 'persons-photos');
```

#### 3. Database Schema

**Required Table**: `persons`

```sql
CREATE TABLE persons (
  id BIGINT PRIMARY KEY GENERATED ALWAYS AS IDENTITY,
  name TEXT,
  context TEXT,
  photo_url TEXT,          -- URL to Supabase storage
  photo_path TEXT,         -- Local file path (for backend)
  audio_url TEXT,          -- URL to audio storage
  audio_path TEXT,         -- Local audio path
  embedding BYTEA,         -- Face embedding (hex-encoded)
  created_at TIMESTAMPTZ DEFAULT NOW(),
  updated_at TIMESTAMPTZ DEFAULT NOW()
);

-- Index for faster queries
CREATE INDEX idx_persons_name ON persons(name);
CREATE INDEX idx_persons_created_at ON persons(created_at DESC);
```

#### 4. Row Level Security (RLS)

**Enable RLS**:
```sql
ALTER TABLE persons ENABLE ROW LEVEL SECURITY;
```

**Create Policies**:
```sql
-- Allow anonymous users to read all persons
CREATE POLICY "Allow anon read access"
ON persons FOR SELECT
TO anon
USING (true);

-- Allow authenticated users to update
CREATE POLICY "Allow authenticated update"
ON persons FOR UPDATE
TO authenticated
USING (true);

-- Allow authenticated users to delete
CREATE POLICY "Allow authenticated delete"
ON persons FOR DELETE
TO authenticated
USING (true);
```

**Note**: Currently, the frontend uses `anon` key for all operations. For production, implement proper authentication and restrict policies to authenticated users only.

---

## Supabase Integration

### Client Initialization

```javascript
// Initialize Supabase client (CDN-loaded library)
const supabase = window.supabase.createClient(SUPABASE_URL, SUPABASE_ANON_KEY);
```

**CDN Source**:
```html
<script src="https://cdn.jsdelivr.net/npm/@supabase/supabase-js@2"></script>
```

### Database Queries

#### **Fetch All Persons**
```javascript
const { data: persons, error } = await supabase
  .from('persons')
  .select('*');
```

**Returns**:
```javascript
[
  {
    id: 1,
    name: "Max Mustermann",
    context: "Analyse: ...\nTranskript: ...",
    photo_url: "https://...supabase.co/storage/v1/object/public/persons-photos/...",
    photo_path: "data/persons/person_1_MaxMustermann/profile.jpg",
    embedding: "\\x0a1b2c...",
    created_at: "2025-01-15T10:30:00Z",
    updated_at: "2025-01-15T10:30:00Z"
  },
  // ...
]
```

#### **Update Person**
```javascript
const { data, error } = await supabase
  .from('persons')
  .update({
    name: "New Name",
    context: "Updated context"
  })
  .eq('id', personId)
  .select(); // Return updated row
```

#### **Delete Person**
```javascript
const { error } = await supabase
  .from('persons')
  .delete()
  .eq('id', personId);
```

### Storage Operations

#### **Generate Signed URL**
```javascript
const { data, error } = await supabase.storage
  .from('persons-photos')
  .createSignedUrl(filePath, 3600); // 1 hour expiry

const signedUrl = data.signedUrl;
```

**Why Signed URLs?**
- Work with private buckets
- Provide temporary access
- Don't expose sensitive URLs
- Can be revoked

**Expiry**: 3600 seconds (1 hour)

#### **Download File**
```javascript
const { data, error } = await supabase.storage
  .from('persons-photos')
  .download(filePath);

// data is a Blob
const objectUrl = URL.createObjectURL(data);
```
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

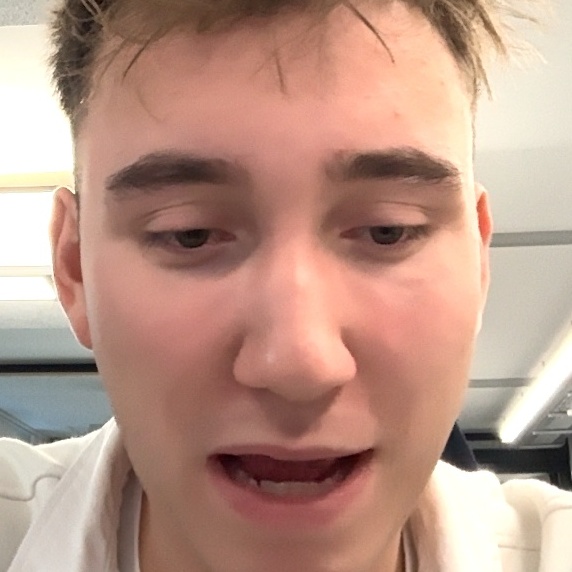
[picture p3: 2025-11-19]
waveshare/cache/photos/person_1.jpg

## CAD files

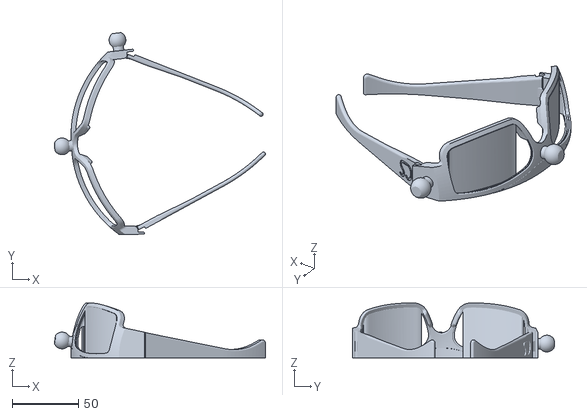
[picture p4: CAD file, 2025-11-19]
3D Models & SVG Files/YUNO - GLASSES.stl
158.8 x 151.9 x 41.4

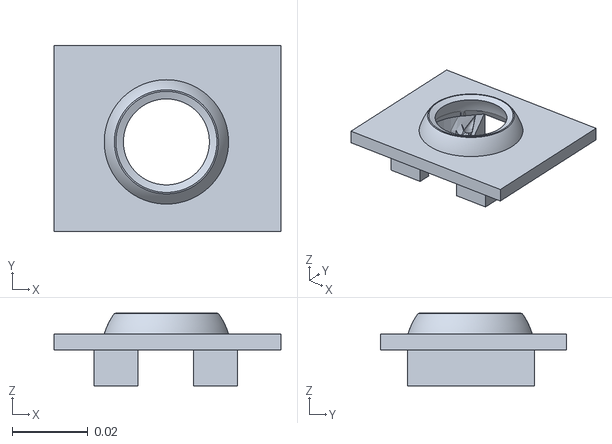
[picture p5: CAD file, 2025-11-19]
3D Models & SVG Files/YUNO - JOYSTICK MODULE.stl
0.0599 x 0.0491 x 0.0192

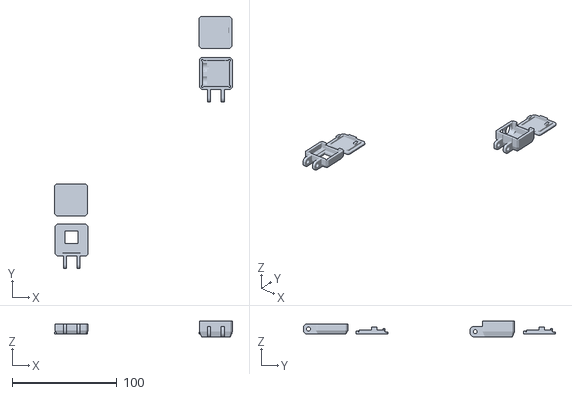
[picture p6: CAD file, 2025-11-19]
3D Models & SVG Files/YUNO - CAMERA AND MIC BOX.stl
169.7 x 240.6 x 15.0

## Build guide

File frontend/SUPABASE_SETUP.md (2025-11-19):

# Setting Up Private Buckets in Supabase

This guide explains how to set your `person-photos` bucket to private while still allowing your frontend to access images.

## Step 1: Make the Bucket Private

1. Go to your Supabase dashboard: https://supabase.com/dashboard
2. Select your project
3. Go to **Storage** in the left sidebar
4. Find your `person-photos` bucket (and `person-audio` if you have one)
5. Click on the bucket name
6. In the bucket settings, find **Public bucket** toggle
7. **Turn OFF** the "Public bucket" toggle (make it private)

## Step 2: Set Up Storage Policies

Even though the bucket is private, you need to allow the `anon` role (your frontend) to read files. This is done through Storage Policies.

1. Still in the Storage section, click on your bucket (`person-photos`)
2. Click on the **Policies** tab
3. You'll see "No policies created yet" - click **New Policy**
4. Choose **For full customization** (or use a template)

### Policy for Reading Files (SELECT)

Create a policy that allows the anon role to download/read files:

**Policy Name:** `Allow anon to read photos`

**Allowed Operation:** SELECT (read/download)

**Policy definition:** Use this SQL:

```sql
(bucket_id = 'person-photos'::text)
```

**WITH CHECK:** (leave empty or same as above)

**USING expression:** Use this SQL:

```sql
auth.role() = 'anon'
```

OR, if you want even more control (only allow authenticated users):

```sql
true
```

The `true` policy will allow anyone with the anon key to read files, which is what you need for your frontend to work.

### Alternative: Using RLS Policy Helper

If Supabase has a policy helper:

1. Select **"SELECT"** as the operation
2. Select **"anon"** as the role
3. Check **"WITH CHECK"** and set it to `true`
4. Save the policy

## Step 3: Verify It Works

1. Make sure your bucket's "Public bucket" toggle is **OFF** (private)
2. Your frontend should still work because:
   - The signed URLs are generated using your anon key
   - The storage policy allows `anon` role to SELECT (read) files
   - The frontend uses `createSignedUrl()` which works with private buckets and proper policies

## Step 4: Do the Same for Audio Bucket (if needed)

If you have a `person-audio` bucket:
1. Repeat the same steps
2. Create a policy for `person-audio` bucket
3. Use the same policy structure

## Security Notes

- **Private buckets are more secure** - files can't be accessed without proper authentication
- **Signed URLs expire** - in the code, they expire after 1 hour (3600 seconds)
- **RLS policies control access** - even with signed URLs, the policy must allow the operation
- **Anon key is public** - anyone can see it in your frontend code, so policies are important

## Troubleshooting

If images don't load after making the bucket private:

1. Check that the policy was created correctly
2. Verify the policy allows `anon` role
3. Check browser console for error messages
4. Make sure the bucket name matches exactly: `person-photos`
5. Verify your anon key is correct in the frontend code

The frontend code already handles private buckets correctly by using `createSignedUrl()` when it detects a non-public bucket.

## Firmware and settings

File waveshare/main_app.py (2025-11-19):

"""
Combined Landing Screen + Slideshow for Yuno
Displays landing screen on startup, switches to slideshow on button press via MQTT.

Controls:
- Any button press on landing screen → Start slideshow
- LEFT joystick in slideshow → Previous image
- RIGHT joystick in slideshow → Next image
- DOWN joystick in slideshow → Toggle name on Arduino LCD
- UP joystick in slideshow → Text-to-Speech reads context
"""
import time
import threading
from pathlib import Path
from typing import List, Optional, Tuple

import numpy as np
from PIL import Image, ImageDraw, ImageFont
import adafruit_blinka_raspberry_pi5_piomatter as pm
import paho.mqtt.client as mqtt
import pyttsx3
import os
from dotenv import load_dotenv, find_dotenv
from openai import OpenAI as _OpenAIClient
import tempfile
import subprocess
import shutil
import signal
try:
    # Optional: reuse existing OpenAI client config
    from src.openai_api import client as openai_client
    from src.openai_api import generate_speech_audio as openai_tts_generate
except Exception:
    openai_client = None
    openai_tts_generate = None

# Fallback: try to initialize OpenAI client here if import failed
if openai_client is None:
    try:
        # Load .env from common locations
        env_path = find_dotenv(filename=".env") or find_dotenv(filename="config/.env")
        if env_path:
            load_dotenv(env_path)
        api_key = os.getenv("OPENAI_API_KEY")
        if api_key:
            openai_client = _OpenAIClient(api_key=api_key)
            print("✅ OpenAI client initialized via local fallback.")
        else:
            print("ℹ️ OPENAI_API_KEY not found in environment.")
    except Exception as e:
        print(f"⚠️ Failed to initialize OpenAI client: {e}")

# Local imports
from data_loader import DataLoader
from pixel_art_generator import PixelArtGenerator


# ── Display Configuration ─────────────────────────────────────────────────────
W, H       = 64, 64
ADDR       = 5
LANES      = 2
PINOUT     = pm.Pinout.Active3BGR
BRIGHTNESS = 180
FPS        = 30
FRAME_DT   = 1.0 / FPS

# ── MQTT Configuration ────────────────────────────────────────────────────────
BROKER = "localhost"
TOPIC = "arduino/to/pi"


# ── Global State ──────────────────────────────────────────────────────────────
class AppState:
    def __init__(self):
        self.mode = "landing"  # "landing" or "slideshow"
        self.running = True
        self.slideshow_idx = 0
        self.slideshow_change_requested = False
        self.name_showing = False  # Track if name is currently displayed on Arduino
        self.lock = threading.Lock()
        # Pending swipe transition requested by input handler
        self._pending_transition = None  # (direction: 'left'|'right', next_idx: int)
    
    def switch_to_slideshow(self):
        with self.lock:
            if self.mode != "slideshow":
                self.mode = "slideshow"
                print("🎬 Switching to slideshow mode...")
                return True
            return False
    
    def get_mode(self):
        with self.lock:
            return self.mode
    
    def next_image(self, total_images):
        with self.lock:
            if total_images > 0:
                self.slideshow_idx = (self.slideshow_idx + 1) % total_images
                self.slideshow_change_requested = True
                print(f"➡️  Next image: {self.slideshow_idx + 1}/{total_images}")
    
    def prev_image(self, total_images):
        with self.lock:
            if total_images > 0:
                self.slideshow_idx = (self.slideshow_idx - 1) % total_images
                self.slideshow_change_requested = True
                print(f"⬅️  Previous image: {self.slideshow_idx + 1}/{total_images}")
    
    def get_slideshow_idx(self):
        with self.lock:
            return self.slideshow_idx
    
    def check_and_reset_change_flag(self):
        with self.lock:
            flag = self.slideshow_change_requested
            self.slideshow_change_requested = False
            return flag
    
    def set_name_showing(self, showing: bool):
        with self.lock:
            self.name_showing = showing
    
    def is_name_showing(self) -> bool:
        with self.lock:
            return self.name_showing
    
    def stop(self):
        with self.lock:
            self.running = False

    def request_transition(self, direction: str, next_idx: int):
        with self.lock:
            self._pending_transition = (direction, next_idx)

    def pop_transition(self):
        with self.lock:
            t = self._pending_transition
            self._pending_transition = None
            return t


state = AppState()


# ── Hardware Mapping ──────────────────────────────────────────────────────────
def map_interleave_columns_no_transform(w, h, lanes):
    lane_w = w // lanes
    lane_pixels = (w * h) // lanes
    out = np.empty(w * h, dtype=np.uint32)
    for y in range(h):
        for x in range(w):
            lane = x % lanes
            x_l = x // lanes
            phys = lane * lane_pixels + y * lane_w + x_l
            out[y * w + x] = phys
    return out.tolist()


def flush_black(fb, device, frames=3, delay=0.015):
    fb.fill(0)
    for _ in range(frames):
        device.show()
        time.sleep(delay)


def apply_brightness_inplace(dst_fb: np.ndarray, src_img: Image.Image, brightness: int):
    if isinstance(src_img, Image.Image):
        arr = np.asarray(src_img, dtype=np.uint16)
    else:
        arr = src_img.astype(np.uint16)
    
    if brightness < 255:
        arr = (arr * brightness) // 255
    np.copyto(dst_fb, arr.astype(np.uint8), casting="no")


def swipe_transition(device, fb, current_arr: np.ndarray, next_arr: np.ndarray, direction: str, steps: int = 10, fps: int = 45):
    """Perform a horizontal swipe between two 64x64 RGB arrays."""
    frame_dt = 1.0 / max(1, fps)
    for i in range(steps + 1):
        t = i / steps
        shift = int(t * W)
        frame = np.zeros_like(current_arr)
        if direction == 'left':
            if shift < W:
                frame[:, :W-shift] = current_arr[:, shift:]
            if shift > 0:
                frame[:, W-shift:] = next_arr[:, :shift]
        else:
            if shift < W:
                frame[:, shift:] = current_arr[:, :W-shift]
            if shift > 0:
                frame[:, :shift] = next_arr[:, W-shift:]
        apply_brightness_inplace(fb, frame, BRIGHTNESS)
        device.show()
        time.sleep(frame_dt)


def tint_image(arr: np.ndarray, tint_rgb: tuple, alpha: float) -> np.ndarray:
    """Blend image with a solid tint color: out = (1-alpha)*img + alpha*tint."""
    img16 = arr.astype(np.uint16)
    tint = np.zeros_like(arr, dtype=np.uint16)
    tint[..., 0] = tint_rgb[0]
    tint[..., 1] = tint_rgb[1]
    tint[..., 2] = tint_rgb[2]
    a_num = int(alpha * 255)
    out = ((img16 * (255 - a_num)) + (tint * a_num)) // 255
    return out.astype(np.uint8)


# ── Landing Screen Functions ──────────────────────────────────────────────────
title_text = "Yuno"
tagline = "Smart Person Recognition & Database"
prompt = "Press any button to start Practicing names"

try:
    title_font = ImageFont.truetype("DejaVuSans-Bold.ttf", 22)
    subtitle_font = ImageFont.truetype("DejaVuSans-Bold.ttf", 12)
    prompt_font = ImageFont.truetype("DejaVuSans.ttf", 7)
except Exception:
    title_font = ImageFont.load_default()
    subtitle_font = ImageFont.load_default()
    prompt_font = ImageFont.load_default()

big_colors = [
    (255, 128, 255), # Pink
    (102, 200, 255), # Blue
    (255, 244, 100), # Yellow
    (120, 255, 120), # Green
    (255, 120, 180), # Magenta
    (255, 80, 80),   # Red
    (240, 240, 240), # White
]


def center(draw, text, font, y):
    try:
        w, h = draw.textbbox((0,0), text, font=font)[2:]
    except Exception:
        w, h = draw.textsize(text, font=font)
    return (W-w)//2, y


def render_landing_frame(t, phase, subtitle_scroll_x, prompt_scroll_x):
    img = Image.new("RGB", (W,H), (0,0,0))
    d = ImageDraw.Draw(img)

    # Animated title
    color_idx = int((t*2 + phase) % len(big_colors))
    title_color = big_colors[color_idx]
    fade = int(200 + 55*(0.5+0.5*np.sin(2*np.pi*t/2)))
    col = tuple(int(c*fade/255) for c in title_color)
    x_title, y_title = center(d, title_text, title_font, 4)
    d.text((x_title, y_title), title_text, fill=col, font=title_font)

    # Scrolling subtitle
    subtitle_w, subtitle_h = d.textbbox((0,0), tagline, font=subtitle_font)[2:]
    subtitle_canvas = Image.new("RGB", (subtitle_w + W, subtitle_h), (0,0,0))
    d_sub = ImageDraw.Draw(subtitle_canvas)
    d_sub.text((W//2,0), tagline, fill=(180,230,255), font=subtitle_font)
    scroll_area = subtitle_w + W
    sx = int(subtitle_scroll_x) % scroll_area
    box = (sx, 0, sx+W, subtitle_h)
    subtitle_strip = subtitle_canvas.crop(box)
    y_subtitle = 34
    img.paste(subtitle_strip, (0, y_subtitle))

    # Scrolling prompt
    prompt_w, prompt_h = d.textbbox((0,0), prompt, font=prompt_font)[2:]
    full_prompt_canvas = Image.new("RGB", (prompt_w*2, prompt_h), (0,0,0))
    d_prompt = ImageDraw.Draw(full_prompt_canvas)
    pulse = int(140+60*(0.5+0.5*np.sin(2*np.pi*t/1.4)))
    d_prompt.text((0, 0), prompt, fill=(pulse,pulse,pulse), font=prompt_font)
    d_prompt.text((prompt_w, 0), prompt, fill=(pulse,pulse,pulse), font=prompt_font)
    p_scroll_area = prompt_w
    psx = int(prompt_scroll_x) % p_scroll_area
    pbox = (psx, 0, psx+W, prompt_h)
    prompt_strip = full_prompt_canvas.crop(pbox)
    y_prompt = H - prompt_h - 1
    img.paste(prompt_strip, (0, y_prompt))

    # Animated border
    border_col = tuple(
        int(48 + 8*np.sin(np.pi*t + k)) for k in (0,2,4)
    )
    d.rectangle((0,0,W-1,H-1), outline=border_col, width=1)
    return img


# ── Slideshow Functions ───────────────────────────────────────────────────────
def load_pixel_art_images() -> Tuple[List[np.ndarray], List[dict]]:
    """Fetch persons with photos and convert each to 64x64 pixel-art arrays.
    Returns tuple of (images, person_data)."""
    loader = DataLoader()
    if not loader.is_connected():
        print("❌ Supabase not connected. Check configuration.")
        return [], []

    persons = loader.load_persons_with_photos()
    if not persons:
        print("⚠️  No persons with photos available.")
        return [], []

    generator = PixelArtGenerator(target_size=(W, H))
    images: List[np.ndarray] = []
    person_data: List[dict] = []

    for person in persons:
        name = person.get("name", "Unknown")
        local_photo = person.get("local_photo_path")
        if not local_photo:
            print(f"   ⚠️  Skipping {name}: no local photo path")
            continue

        pixel_art = generator.generate_pixel_art(local_photo, enhance=True)
        if pixel_art is None:
            print(f"   ⚠️  Failed to generate pixel art for {name}")
            continue

        images.append(pixel_art)
        person_data.append(person)
        print(f"   ✅ Prepared {name}")

    return images, person_data


# ── Text-to-Speech Setup ─────────────────────────────────────────────────────
tts_engine = None
tts_lock = threading.Lock()

def init_tts():
    """Initialize TTS engine"""
    global tts_engine
    try:
        tts_engine = pyttsx3.init()
        # Set properties (adjust for better voice)
        tts_engine.setProperty('rate', 150)    # Speed (words per minute)
        tts_engine.setProperty('volume', 0.9)  # Volume (0.0 to 1.0)
        
        # Try to set a female voice if available
        voices = tts_engine.getProperty('voices')
        for voice in voices:
            if 'female' in voice.name.lower() or 'zira' in voice.name.lower():
                tts_engine.setProperty('voice', voice.id)
                break
        
        print("🔊 TTS Engine initialized")
    except Exception as e:
        print(f"⚠️  TTS initialization failed: {e}")

def _sanitize_context(name: str, context: str) -> str:
    """Remove the person's name from the context (case-insensitive) and tidy spaces."""
    try:
        import re
        cleaned = context
        # Remove full name occurrences
        if name:
            name_pattern = re.escape(name)
            cleaned = re.sub(name_pattern, "", cleaned, flags=re.IGNORECASE)
            # Also remove first/last name individually
            parts = [p for p in name.split() if p]
            for p in parts:
                cleaned = re.sub(rf"\b{re.escape(p)}\b", "", cleaned, flags=re.IGNORECASE)
        # Collapse multiple spaces and tidy punctuation
        cleaned = re.sub(r"\s+", " ", cleaned).strip()
        cleaned = re.sub(r"\s+([,.;:!?])", r"\1", cleaned)
        return cleaned
    except Exception:
        return context


def speak_context(name: str, context: str):
    """Speak person's context using TTS in a separate thread.
    Prefers high-quality cloud TTS (OpenAI) if available, otherwise falls back to pyttsx3.
    Adds a short intro and removes the person's name from the content.
    """
    def _speak():
        with tts_lock:
            try:
                # Lower background music volume during TTS
                lower_music_volume()
                try:
                    # 1) Cleanup text (LLM if available, else local sanitize)
                    safe_context = context
                    if openai_client is not None:
                        try:
                            prompt = (
                                "You will receive a person's name and a short context about them. "
                                "Rewrite the context into clean, grammatically correct English suitable for being read aloud in one to two sentences. "
                                "Do NOT include the person's name or any direct identifiers. "
                                "Keep it concise, natural, and easy to listen to.\n\n"
                                f"Name: {name}\n"
                                f"Context: {context}"
                            )
                            resp = openai_client.chat.completions.create(
                                model="gpt-4o-mini",
                                messages=[
                                    {"role": "system", "content": "You are a helpful assistant that rewrites short snippets for natural text-to-speech. Only output the rewritten text."},
                                    {"role": "user", "content": prompt},
                                ],
                                temperature=0.2,
                                max_tokens=120,
                            )
                            candidate = resp.choices[0].message.content.strip()
                            if candidate:
                                safe_context = candidate
                                print("✅ LLM cleanup used for TTS text.")
                            else:
                                safe_context = _sanitize_context(name, context)
                                print("⚠️ LLM returned empty text. Falling back to local sanitizer.")
                        except Exception:
                            safe_context = _sanitize_context(name, context)
                            print("⚠️ LLM cleanup failed. Using local sanitizer.")
                    else:
                        safe_context = _sanitize_context(name, context)
                        print("ℹ️ LLM not configured. Using local sanitizer.")

                    intro = "Here is some quick context."
                    text = f"{intro} {safe_context}"
                    print("🗣️ TTS will say:\n" + text)

                    # 2) Try multiple TTS options in order of quality
                    
                    # Option A: OpenAI TTS (nova voice - very natural, female-like)
                    if openai_client is not None and openai_tts_generate is not None:
                        try:
                            audio_bytes = openai_tts_generate(text, voice="nova")  # Very natural female voice
                            with tempfile.NamedTemporaryFile(delete=False, suffix=".mp3") as tmp:
                                tmp.write(audio_bytes)
                                tmp_path = tmp.name
                            # Try multiple audio players
                            for player in ["mpg123", "mpv", "aplay", "ffplay"]:
                                try:
                                    if player == "aplay":
                                        # Convert to wav first for aplay
                                        subprocess.check_call(["ffmpeg", "-i", tmp_path, "-f", "wav", "-acodec", "pcm_s16le", tmp_path.replace(".mp3", ".wav")], 
                                                            stdout=subprocess.DEVNULL, stderr=subprocess.DEVNULL)
                                        rc = subprocess.call([player, "-q", tmp_path.replace(".mp3", ".wav")])
                                    else:
                                        rc = subprocess.call([player, "-q", tmp_path], stdout=subprocess.DEVNULL, stderr=subprocess.DEVNULL)
                                    if rc == 0:
                                        print("✅ Played with OpenAI TTS (nova voice)")
                                        os.unlink(tmp_path)
                                        return
                                except (subprocess.CalledProcessError, FileNotFoundError):
                                    continue
                            os.unlink(tmp_path)
                            print("⚠️ No audio player found. Trying alternatives...")
                        except Exception as e:
                            print(f"⚠️ OpenAI TTS failed: {e}. Trying alternatives...")
                    
                    # Option B: gTTS (Google Text-to-Speech - free, decent quality)
                    try:
                        from gtts import gTTS
                        tts_gtts = gTTS(text=text, lang='en', slow=False)
                        with tempfile.NamedTemporaryFile(delete=False, suffix=".mp3") as tmp:
                            tts_gtts.save(tmp.name)
                            tmp_path = tmp.name
                        for player in ["mpg123", "mpv", "ffplay"]:
                            try:
                                rc = subprocess.call([player, "-q", tmp_path], stdout=subprocess.DEVNULL, stderr=subprocess.DEVNULL)
                                if rc == 0:
                                    print("✅ Played with gTTS")
                                    os.unlink(tmp_path)
                                    return
                            except (subprocess.CalledProcessError, FileNotFoundError):
                                continue
                        os.unlink(tmp_path)
                    except Exception as e:
                        print(f"⚠️ gTTS failed: {e}")

                    # 3) Fallback: local pyttsx3
                    if tts_engine:
                        tts_engine.say(text)
                        tts_engine.runAndWait()
                    else:
                        print("⚠️ No TTS engine available.")
                finally:
                    # Always restore music volume after TTS
                    restore_music_volume()
            except Exception as e:
                print(f"⚠️  TTS error: {e}")
                # Restore volume even on error
                restore_music_volume()

    # Run in separate thread to avoid blocking
    threading.Thread(target=_speak, daemon=True).start()


# ── MQTT Handler / Quiz Mode State ────────────────────────────────────────────
# Store total images count and person data globally so MQTT handler can access it
total_slideshow_images = 0
slideshow_person_data = []
mqtt_client = None

# Quiz queue: list of indices into slideshow_person_data
quiz_queue = []

# Background music process
bgm_proc = None

def sounds_path(filename: str) -> str:
    return os.path.join(os.path.dirname(__file__), "sounds", filename)

def start_background_music(trigger: str):
    """Start background music depending on trigger (LEFT/RIGHT/UP/DOWN/PRESS)."""
    global bgm_proc
    # Stop any existing music first
    stop_background_music()
    # Simple mapping
    if "LEFT" in trigger:
        song = sounds_path("Subway.wav")
    elif "RIGHT" in trigger:
        song = sounds_path("Espresso.wav")
    elif "DOWN" in trigger:
        song = sounds_path("Fortnite Festival.wav")
    elif "UP" in trigger or "PRESS" in trigger:
        song = sounds_path("Fortnite OG.wav")
    else:
        song = sounds_path("Juno.wav")
    try:
        # Prefer robust players that handle compressed WAV (ffplay/mpv), then mpg123 (mp3), fallback aplay
        cmd = None
        if shutil.which("ffplay"):
            cmd = ["ffplay", "-nodisp", "-autoexit", "-loglevel", "quiet", song]
        elif shutil.which("mpv"):
            cmd = ["mpv", "--no-video", "--really-quiet", song]
        elif song.lower().endswith(".mp3") and shutil.which("mpg123"):
            cmd = ["mpg123", "-q", song]
        elif shutil.which("aplay"):
            cmd = ["aplay", "-q", song]

        if cmd is None:
            print("⚠️  No audio player found (ffplay/mpv/mpg123/aplay). Cannot play background music.")
            return

        bgm_proc = subprocess.Popen(cmd, stdout=subprocess.DEVNULL, stderr=subprocess.DEVNULL)
        print(f"🎵 Background music started: {os.path.basename(song)} (via {cmd[0]})")
    except Exception as e:
        print(f"⚠️  Could not start background music: {e}")

def stop_background_music():
    global bgm_proc
    if bgm_proc is not None and bgm_proc.poll() is None:
        try:
            bgm_proc.terminate()
            print("⏹️  Background music stopped")
        except Exception:
            pass
    bgm_proc = None
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

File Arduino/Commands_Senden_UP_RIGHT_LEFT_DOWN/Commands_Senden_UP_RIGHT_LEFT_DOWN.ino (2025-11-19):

#include <Arduino.h>
#include <WiFiNINA.h>
#include <PubSubClient.h>
#include <LiquidCrystal.h>

// -------------------- LCD + JOYSTICK PINS --------------------
LiquidCrystal lcd(12, 11, 5, 4, 3, 2);

// Joystick axes swapped to match physical orientation
const int xPin = A1;   // Joystick X-axis (left/right)
const int yPin = A0;   // Joystick Y-axis (up/down)
const int swPin = 7;   // Joystick Button

// -------------------- WLAN + MQTT SETTINGS --------------------
const char* WIFI_SSID     = "Robin";
const char* WIFI_PASSWORD = "12345678";
const char* MQTT_HOST     = "172.20.10.2";
const uint16_t MQTT_PORT  = 1883;

const char* TOPIC_IN  = "pi/to/arduino";
const char* TOPIC_OUT = "arduino/to/pi";

// -------------------- DISPLAY STATE --------------------
String lineTop = "";
String lineBottom = "";
int scrollPos = 0;

// -------------------- MQTT CLIENT --------------------
WiFiClient wifiClient;
PubSubClient mqtt(wifiClient);

// -------------------- HELPER FUNCTIONS --------------------
String crop(const String& s, int start) {
  if (start < 0) start = 0;
  int end = start + 16;
  if (end > s.length()) end = s.length();
  String out = s.substring(start, end);
  while (out.length() < 16) out += " ";
  return out;
}

void render() {
  lcd.clear();
  lcd.setCursor(0, 0);
  lcd.print(crop(lineTop, 0));
  lcd.setCursor(0, 1);
  lcd.print(crop(lineBottom, scrollPos));
}

void flickerDisplay() {
  for (int i = 0; i < 10; i++) {
    lcd.noDisplay();
    delay(100);
    lcd.display();
    delay(100);
  }
  render();
}

void handleCommand(const String& cmd) {
  Serial.print("Received command: "); // DEBUG
  Serial.println(cmd);                // DEBUG

  if (cmd.startsWith("NAME:")) {
    lineTop = cmd.substring(5);
    scrollPos = 0;
  } else if (cmd.startsWith("DESC:")) {
    lineBottom = cmd.substring(5);
    scrollPos = 0;
  } else if (cmd == "CLEAR") {
    lineTop = "";
    lineBottom = "";
  } else if (cmd == "FLICKER") {
    flickerDisplay();
    return;
  }
  render();
}

void onMqttMessage(char* topic, byte* payload, unsigned int length) {
  Serial.println("MQTT message received"); // DEBUG

  String msg;
  for (unsigned int i = 0; i < length; i++) msg += (char)payload[i];
  msg.trim();
  handleCommand(msg);
}

void ensureMqtt() {
  if (mqtt.connected()) return;

  Serial.println("MQTT not connected! Attempting reconnect..."); // DEBUG

  while (!mqtt.connected()) {
    Serial.print("Connecting to MQTT... "); // DEBUG
    if (mqtt.connect("arduino-lcd-client")) {
      Serial.println("connected!"); // DEBUG
      mqtt.subscribe(TOPIC_IN);
      Serial.println("Subscribed to: pi/to/arduino"); // DEBUG
    } else {
      Serial.print("MQTT failed, rc="); // DEBUG
      Serial.println(mqtt.state());
      delay(2000);
    }
  }
}

// -------------------- SETUP --------------------
void setup() {
  Serial.begin(9600);
  lcd.begin(16, 2);
  pinMode(swPin, INPUT_PULLUP);

  Serial.print("Connecting to WiFi "); // DEBUG
  Serial.print(WIFI_SSID);            // DEBUG
  Serial.println(" ...");             // DEBUG

  WiFi.begin(WIFI_SSID, WIFI_PASSWORD);

  int timeout = 0;
  while (WiFi.status() != WL_CONNECTED) {
    delay(500);
    Serial.print(".");                // DEBUG
    timeout++;
    if (timeout > 30) {
      Serial.println("\n❌ WiFi connection FAILED!"); // DEBUG
      break;
    }
  }

  if (WiFi.status() == WL_CONNECTED) {
    Serial.println("\n✔️ WiFi connected!");         // DEBUG
    Serial.print("IP address: ");
    Serial.println(WiFi.localIP());
  } else {
    Serial.println("⚠️ Not connected to WiFi!");     // DEBUG
  }

  mqtt.setServer(MQTT_HOST, MQTT_PORT);
  mqtt.setCallback(onMqttMessage);

  ensureMqtt();

  lineTop = "YUNO";
  lineBottom = "Smart Learning";
  render();
}

// -------------------- MAIN LOOP --------------------
enum JoyState { NEUTRAL, UP, DOWN, LEFT, RIGHT };
static JoyState lastState = NEUTRAL;

void loop() {
  // ---------------- Debug: WiFi & MQTT status ----------------
  if (WiFi.status() != WL_CONNECTED) {
    Serial.println("⚠️ Lost WiFi connection!"); // DEBUG
  }

  if (!mqtt.connected()) {
    Serial.println("⚠️ MQTT lost, reconnecting..."); // DEBUG
    ensureMqtt();
  }

  mqtt.loop();

  // ---------------- Joystick reading ----------------
  int xVal = analogRead(xPin);
  int yVal = analogRead(yPin);
  int btn  = digitalRead(swPin);

  // Debug raw values
  Serial.print("JOY X:");
  Serial.print(xVal);
  Serial.print(" Y:");
  Serial.print(yVal);
  Serial.print(" BTN:");
  Serial.println(btn);

  bool changed = false;
  JoyState currentState = NEUTRAL;

  if (yVal < 400) currentState = DOWN;
  else if (yVal > 600) currentState = UP;
  else if (xVal < 400) currentState = LEFT;
  else if (xVal > 600) currentState = RIGHT;

  if (currentState != lastState && currentState != NEUTRAL) {
    switch (currentState) {
      case UP:
        mqtt.publish(TOPIC_OUT, "JOY:UP");
        Serial.println("JOY:UP"); // DEBUG
        break;
      case DOWN:
        mqtt.publish(TOPIC_OUT, "JOY:DOWN");
        Serial.println("JOY:DOWN"); // DEBUG
        break;
      case LEFT:
        mqtt.publish(TOPIC_OUT, "JOY:LEFT");
        Serial.println("JOY:LEFT"); // DEBUG
        if (scrollPos > 0) scrollPos--;
        changed = true;
        break;
      case RIGHT:
        mqtt.publish(TOPIC_OUT, "JOY:RIGHT");
        Serial.println("JOY:RIGHT"); // DEBUG
        if (scrollPos < max(0, (int)lineBottom.length() - 16)) scrollPos++;
        changed = true;
        break;
      default: break;
    }
  }

  lastState = currentState;

  static int lastBtn = HIGH;
  if (btn == LOW && lastBtn == HIGH) {
    mqtt.publish(TOPIC_OUT, "JOY:PRESS");
    Serial.println("JOY:PRESS"); // DEBUG
  }
  lastBtn = btn;

  if (changed) render();

  delay(50);
}

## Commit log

2025-11-19 addd 3D-Models & SVG Files
    [YUNO - CAMERA AND MIC BOX.stl, YUNO - GLASSES.stl, YUNO - JOYSTICK MODULE.stl]
2026-06-03 Update README and input handler for single button functionality with multi-press actions
2026-06-03 Update camera handling and button listener messages for clarity and accuracy
2026-06-03 Add button input test and logger for gesture recognition
2026-06-03 Remove photo capture functionality from button listener
2026-06-03 Point frontend + Arduino to new Supabase project; Safari fix
    - frontend/index.html: switch SUPABASE_URL + ANON_KEY to new project
    pkfktebcugzldkxezaiz (uses new sb_publishable_* key format). Rename
    local `supabase` client const to `sb` so it no longer shadows the
    global `window.supabase` from the CDN bundle — Safari rejects that
    shadowing with "Can't create duplicate variable that shadows a global
    property" and silently aborts the whole inline script, leaving every
    onclick handler unbound.
    - Arduino sketch: MQTT_HOST 172.20.10.2 → 172.20.10.11 (the iPhone
    hotspot IP of Pi 2, where mosquitto actually runs). The previous
    value pointed at the Mac.
2026-06-03 Add phantom-edge protection to button input test
    On Pi 5 (RPi.GPIO over lgpio), add_event_detect occasionally fires an
    initial phantom edge right after setup that consumes the user's first
    press: the lone UP edge arrives before any DOWN, ButtonGestureLogger
    sees _press_start_time is None and silently returns, and the first
    press appears to be ignored.
    Two complementary guards in run_gpio():
    1. 300ms grace period after GPIO setup; edges in that window are
    logged and dropped instead of fed to the logger.
    2. If an UP edge still arrives without a matching DOWN later
    (debounce ate the down), synthesize a press_start_time = now so
    it's counted as a 0s short press instead of bei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
2026-06-03 Apply phantom-edge protection to ButtonHandler
    Same fix as the test logger (tests/test_button_input.py) — port to
    src/input_handler.ButtonHandler so the main button mode no longer
    swallows the first press on Pi 5 boot:
    1. _ready_at = time.time() + 0.3 set right before add_event_detect.
    _on_edge() returns early for any callback that fires inside that
    300 ms window. Handles the Init-Edge that lgpio sometimes emits.
    2. If an UP edge arrives with _press_start_time still None (debounce
    consumed the DOWN), synthesize a press_start_time = now so the
    event is treated as a 0 s short press instead of being dropped.
